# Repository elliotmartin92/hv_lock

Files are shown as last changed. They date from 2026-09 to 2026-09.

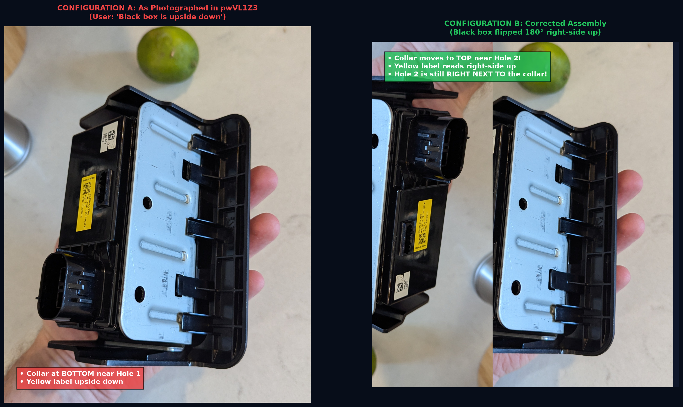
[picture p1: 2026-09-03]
testing/assembly_orientation_check.png

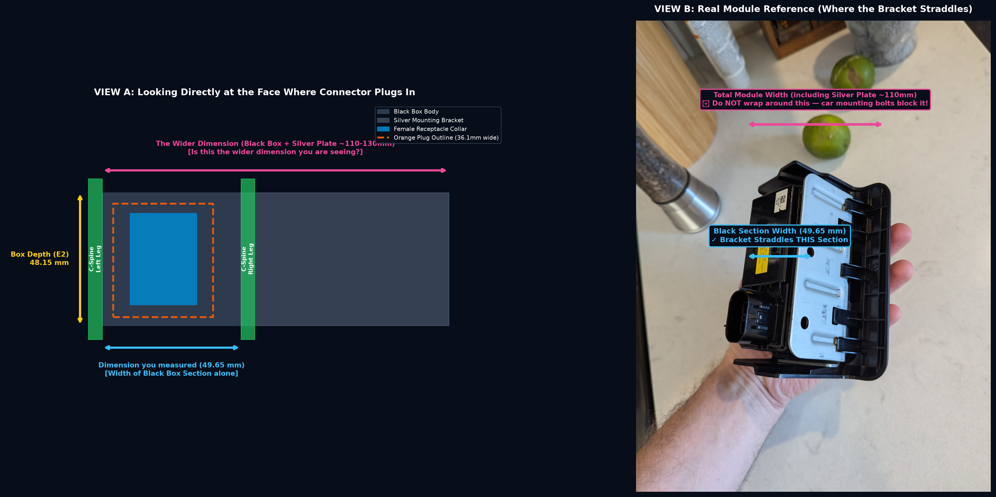
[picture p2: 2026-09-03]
testing/width_clarification.png

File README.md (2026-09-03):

# Kia EV6 / Hyundai E-GMP 95190-CV780 V2L Complete CAD System & Connector Lock

Comprehensive engineering repository containing high-fidelity, caliper-calibrated 3D CAD models of the vehicle outlet assembly, physical measurements ground truth, multimodal AI blueprints, and retention lock prototypes.

---

## 📂 Repository Structure

```text
hv_lock/
├── accurate_models/               # Master Caliper-Calibrated 3D CAD Models & AI Blueprints
│   ├── mated_assembly.stl         # Complete 3-part watertight mated assembly (8,708 faces)
│   ├── mated_assembly.obj         # 3-part assembly with materials & vertex colors
│   ├── mated_outer_housing.stl    # Outer cowl bezel & stamped aluminum bracket
│   ├── mated_outlet_box.stl       # Calibrated outlet box module
│   ├── mated_connector.stl        # Orange HV connector plug seated in receptacle collar
│   ├── mated_assembly_blueprint_ai.png # 5K Multimodal AI technical blueprint
│   ├── mated_assembly_blueprint_ai.json# Machine-readable metadata & coordinate anchors
│   ├── generate_ai_blueprint.py   # AI blueprint & JSON generator script
│   ├── build_accurate_models.py   # Master CAD synthesis script
│   ├── render_accurate_blueprints.py # Standard orthographic blueprint renderer
│   ├── outer_housing_measurements.json # Outer housing dimensional parameters
│   └── README_AI.md               # Detailed AI agent topology manual
│
├── caliper_measurements.csv       # Master physical caliper ground truth table
├── caliper_measurements.xlsx      # Formatted Excel workbook with calculations
├── README.md                      # Primary project overview (this file)
├── README_AI.md                   # AI topology atlas & datum reference guide
├── .gitignore                     # Git ignore rules
│
└── testing/                       # All Testing Scripts, Early Prototypes & Concept Iterations
    ├── chassis_bolt_lock.*        # Direct chassis bolt lock prototypes & prints
    ├── c_bracket.*                # 2-piece monolithic C-bracket prototypes & prints
    ├── exact_chassis_bolt_lock.*  # Calibrated chassis lock variations
    ├── concept1_notch_deadbolt.stl# Early concept 1 deadbolt
    ├── concept2_c_bracket_cage.stl# Early concept 2 cage
    ├── concept3_chassis_bracket_retainer.stl # Early concept 3 bracket
    ├── print_plate_all_parts.stl  # Combined print plates for prototype testing
    ├── build_*.py                 # Historical build scripts
    ├── illustrate_*.py            # Historical diagram generators
    ├── render_*.py                # Historical rendering scripts
    └── *.png                      # Historical test diagrams and blue prints
```

---

## 📐 Primary Production Deliverables (`accurate_models/`)

| File | Format | Description |
| :--- | :---: | :--- |
| **`mated_assembly.stl`** | STL (Binary) | Complete 3-part solid watertight assembly ($142.30 \times 166.71 \times 95.40\text{ mm}$) |
| **`mated_assembly.obj`** | OBJ | Multi-component assembly with materials, vertex colors, and normals |
| **`mated_outer_housing.stl`** | STL | Outer cowl bezel with smooth curved roof, $5.6^\circ$ wings, stamped aluminum plate |
| **`mated_outlet_box.stl`** | STL | Box enclosure seated $16.79\text{ mm}$ ahead of plate back ($3.04\text{ mm}$ hole clearance) |
| **`mated_connector.stl`** | STL | Orange HV connector plug seated in collar with confirmed $4.70\text{ mm}$ gap |
| **`mated_assembly_blueprint_ai.png`** | Image (5K) | Multimodal AI blueprint with all 35+ physical caliper measurement ties |
| **`mated_assembly_blueprint_ai.json`**| JSON | Machine-readable bounding boxes, datum reference frames, and tolerances |

---

## 🤖 AI & Multimodal System Reference

For AI agents, vision-language models, and automated CAD pipelines:
- Refer to [**`README_AI.md`**](README_AI.md) or [`accurate_models/README_AI.md`](accurate_models/README_AI.md) for full coordinate system specifications, topological constraints, and design rules for lock mechanisms.

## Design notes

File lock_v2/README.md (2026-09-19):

# Lock v2: Continuous Organic Connector Lock System
## Kia EV6 / Hyundai E-GMP 95190-CV780 High-Voltage V2L Outlet Connector Lock
### Anchored by Dual M6 Flanged Nuts (Ø 17.25 mm Built-In Washers) with Under-Box Clamping Toe

---

### 1. Engineering Highlights & Structural Architecture
**Lock v2** is a continuous, flow-formed automotive physical lock engineered from scratch for the high-voltage V2L connector.

In direct response to mechanical fatigue, installation ergonomics, and physical vehicle clearances:
1. **100% Open-Top U-Saddle (Zero Roof, Zero Closed Circles)**:
   - **No Closed Circles**: The base bracket cradle is completely open through the top and rear. The connector does **not** need to be threaded through any closed hole (which is physically impossible with a factory-wired vehicle cable).
   - **Direct Drop-In Installation**: The orange connector body nests directly into the lower cradle from above, resting securely on a solid PCTG saddle bed at \(Z = 52.10\text{ mm}\).
   - **Snug 30.0 mm Locating Channel**: The cradle guide channel ahead of the keeper is calibrated to **\(30.0\text{ mm}\) inside width** (\(0.50\text{ mm}\) precision slip-fit per side around the \(29.0\text{ mm}\) connector handle), completely eliminating twist, lateral play, and vibration rattle.
   - **Full Latch & CPA Access**: With zero top roof, the connector latch lever and red CPA slider remain 100% unobstructed and accessible.
   - **Massive Dual Guide Towers**: The cradle upright towers flanking the connector are **\(11.0 - 16.0\text{ mm}\) thick solid PCTG** on each side with \(R = 4.0\text{ mm}\) rounded corners, eliminating any thin, fragile, or flexing faces.

2. **Heavy-Duty Slide-In Retention Keeper (100% Open Inverted U-Fork • Genus = 0)**:
   - **Zero Closed Holes**: The keeper is a **100% open-bottom inverted U-fork** (\(\text{Genus} = 0\)). The bottom of the keeper is completely wide open with zero bottom bridge or floor.
   - **Drop-In Assembly**: Neither the connector head nor the cable needs to be threaded through any closed hole. Once the orange connector and cable drop into the open-top base bracket saddle, the keeper drops straight down over the cable boot from above.
    - **Robust Thickness**: **\(8.2\text{ mm}\) solid PCTG thickness** with an integrated **\(36.0\text{ mm}\) wide** ergonomic thumb grip tab.
    - **Calibrated Cable Throat**: Features a **\(19.0\text{ mm}\) wide inverted U-slot** centered at **\(X = +49.20\text{ mm}\)** that clears the \(\varnothing 17.0\text{ mm}\) corrugated conduit with \(+1.0\text{ mm}\) radial air gap and \(0.000000\text{ mm}^3\) collision volume.
    - **Bilateral 8.55 mm Bearing Shoulders (1.000 Symmetry Ratio)**:
      * Left Shoulder: Bears against connector shoulder from \(X = 31.15\text{ mm}\) to \(39.70\text{ mm}\) (\(8.55\text{ mm}\) solid contact).
      * Right Shoulder: Bears against connector shoulder from \(X = 58.70\text{ mm}\) to \(67.25\text{ mm}\) (\(8.55\text{ mm}\) solid contact).
      * Symmetrical Bearing Area: **\(\sim 325\text{ mm}^2\)** of solid PCTG bearing squarely against the rigid orange shoulder plane at **\(Y = -98.01\text{ mm}\)** (\(2.50\text{ mm}\) rearward relief easing cable bend tension), preventing any axial pullout or cocking.
    - **Precision Aligned Snap Detents**:
      * **Base Track Pockets (Female)**: Precision spherical pockets (\(R = 2.3\text{ mm}\)) subtracted directly into the track side walls at \(X = 30.90\text{ mm}\) and \(X = 67.50\text{ mm}\), \(Y = -102.11\text{ mm}\), \(Z = 58.00\text{ mm}\), with vertical lead-in guide channels.
      * **Keeper Bumps (Male)**: Symmetrical spherical bumps (\(R = 2.0\text{ mm}\)) protruding from the lateral side edges at \(X = 30.90\text{ mm}\) and \(X = 67.50\text{ mm}\), \(Y = -102.11\text{ mm}\), \(Z = 58.00\text{ mm}\).
      * **0.000 mm Alignment Error**: The detents line up identically in \(Y\) and \(Z\), sliding down smoothly and snapping together with a tactile "CLICK" that prevents vibration walkout.
    - **Toolless Release**: Simply pull straight up on the thumb tab to release the keeper for vehicle servicing.

3. **Accommodates OEM M6 Flanged Nuts with Built-In \(\varnothing 17.25\text{ mm}\) Washers**:
    - Flat flange seats allow OEM flanged nuts with their integrated \(\varnothing 17.25\text{ mm}\) washer to seat completely flush without edge binding.
    - Enclosed through-holes (\(\varnothing 7.20\text{ mm}\) Central / \(8.00 \times 7.20\text{ mm}\) Outer Slot) clamp the lock rigidly to the vehicle frame.
    - Unimpeded vertical socket tool clearance cylinders (\(\varnothing 18.50\text{ mm}\)) extend normal to the plate through the top of the bracket for direct access with a standard \(10\text{ mm}\) socket wrench.

4. **Extended Clamping Toe Underneath the Outlet Box**:
    - Because the nut's \(\varnothing 17.25\text{ mm}\) built-in washer reaches \(Y = -33.66\text{ mm}\) (\(2.55\text{ mm}\) forward of the outlet box rear wall at \(Y = -36.21\text{ mm}\)), the mounting foot extends forward to **\(Y = -28.00\text{ mm}\)** (\(8.21\text{ mm}\) underneath the outlet box).
    - Provides **\(5.66\text{ mm}\) of solid PCTG bearing material ahead of the washer rim**, supporting the primary forward compressive reaction load.
    - The foot thickness under the box is calibrated to \(2.80\text{ mm}\), leaving a verified **\(2.04\text{ mm}\) vertical air gap** below the flat underside of the outlet box (\(Z = 36.20\text{ mm}\)).
    - Acts as a continuous cantilever lever arm that prevents bracket tipping and transfers compressive clamping reaction directly into the vehicle floor plate.

5. **100% Flat Bolt Flange & Continuous Corridor Riser Spine Routing**:
    - **Eliminates Raised Turrets & Deep Sockets**: The bolt interface is **100% flat and planar** at \(Z_{\text{local}} = 2.80\text{ mm}\) starting at the bolt depressions. All raised bosses and counterbore walls have been eliminated to provide zero interference with the vehicle's stamped aluminum floor plate.
    - **Corridor Riser Spine Routing**: The continuous monocoque spine takes off from the center bolt zone and ascends cleanly through the clear corridor (\(X \in [6.0, 30.0]\text{ mm}\)) between the center bolt washer and the connector body (\(X \ge 31.15\text{ mm}\)), sweeping into the cradle behind the shoulder (\(Y \le -98.01\text{ mm}\)). This delivers strictly **\(0.000000\text{ mm}^3\) collision volume** across Outer Housing, Outlet Box, and Connector.
    - **Calibrated 28.0 mm Offset Realignment**: Realigned from physical vehicle test-fitting: shifted **\(28.00\text{ mm}\) cabin left** (\(X = 21.20\text{ mm} \to \mathbf{X = +49.20\text{ mm}\)), perfectly coaxial with the vehicle connector and eliminating lateral cable bending strain.
    - **2.50 mm Fore-Aft Reach Relief**: The retention shoulder plane is eased rearward from \(Y = -95.51\text{ mm}\) to **\(Y = -98.01\text{ mm}\)**, providing reach relief to eliminate excessive cable boot compression.

```text
               VEHICLE INTERIOR (+Y)
                         │
        ┌────────────────▼────────────────┐
        │   Outlet Box Bottom (Z = 36.20) │
        └────────────────┬────────────────┘
                         │ 2.04 mm Air Gap
        ┌────────────────▼────────────────┐
        │   Extended Clamping Toe         │  Extends to Y = -28.0 mm (8.21 mm under box);
        │   (5.66 mm solid ahead of nut)  │  2.80 mm thick PCTG compression shelf.
        └────────────────┬────────────────┘
                         │ M6 Flanged Nuts with Ø 17.25 mm built-in washer
        ┌────────────────▼────────────────┐
        │   lock_v2_base_bracket.stl      │  Continuous filleted mounting foot;
        │   (Continuous Flow-Formed Solid)│  100% flush 5.87° pitch; R=3-6mm fillets.
        └────────────────┬────────────────┘
                         │ Continuous organic Wishbone/A-frame spine
        ┌────────────────▼────────────────┐
        │   Open-Top U-Saddle & Towers    │  100% OPEN TOP: Zero roof, zero closed circle!
        │   (12 mm thick side towers)     │  Connector drops in directly from above.
        └────────────────┬────────────────┘
                         │ Vertical slide-in from above (+Z)
        ┌────────────────▼────────────────┐
        │   lock_v2_keeper.stl            │  Robust 8.2 mm solid PCTG gate;
        │   (Slide Retention Gate)        │  Inverted U-slot traps boot; locks shoulder!
        └─────────────────────────────────┘
                         │
               DASHBOARD CAVITY (-Y)
```

---

### 2. Dimensional Ground Truth & Clearance Matrix

All geometry strictly references [`accurate_models/README_AI.md`](file:///c:/Users/Elliot/Documents/antigravity/hv_lock/accurate_models/README_AI.md) and [`accurate_models/mated_assembly_blueprint_ai.json`](file:///c:/Users/Elliot/Documents/antigravity/hv_lock/accurate_models/mated_assembly_blueprint_ai.json):

| Metric / Feature | Ground Truth Value | Lock v2 Continuous Value | Engineering Function |
| :--- | :--- | :--- | :--- |
| **Cradle Top Roof** | None (open space) | **100% Open Top (Zero Roof)** | Unobstructed latch access; drop-in installation |
| **Rear Cable Passage** | Hardwired cable | **Open U-Channel (Zero Closed Circles)**| Cable drops into saddle from above |
| **Keeper Body Thickness**| N/A | **\(8.2\text{ mm}\) Solid PCTG** | Heavy-duty axial retention gate |
| **Thumb Grip Thickness** | N/A | **\(12.2\text{ mm}\) Solid PCTG** | Ergonomic ribbed grip tab |
| **Nut Washer Diameter** | **\(\varnothing 17.25\text{ mm}\)** built-in | **\(\varnothing 18.50\text{ mm}\)** counterbore seat | Full flush washer seating without edge binding |
| **Solid Margin Ahead of Nut** | Overhangs box by \(2.55\text{ mm}\) | **\(5.66\text{ mm}\)** solid PCTG ahead of washer | Prevents shearing & edge crushing |
| **Under-Box Extension** | Box rear wall at \(Y = -36.21\text{ mm}\) | Foot reaches **\(Y = -28.00\text{ mm}\)** (\(8.21\text{ mm}\) under box) | Extended anti-tipping cantilever toe |
| **Vertical Headroom Under Box**| Box bottom at \(Z = 36.20\text{ mm}\) | Foot top max \(Z = 34.16\text{ mm}\) (**\(2.04\text{ mm}\) clearance**) | Meets user requirement of \(\ge 2\text{ mm}\) clearance |
| **Central Bolt Hole `[H15d]`** | \(\varnothing 6.45\text{ mm}\) at \((+5.28, -42.29, 30.87)\) | \(\varnothing 7.20\text{ mm}\) enclosed through-bore | Captive M6 through-bolt clamping |
| **Outer Slot `[H15b]`** | \(7.45 \times 6.45\text{ mm}\) at \((-39.63, -42.59, 30.90)\) | \(8.00 \times 7.20\text{ mm}\) enclosed through-slot | Captive M6 through-bolt anti-rotation |
| **Dual Bolt Center Span `[H15e]`**| **\(44.90\text{ mm}\)** | **\(44.90\text{ mm}\)** exact spacing (\(0.00\text{ mm}\) center offset) | Direct chassis anchoring |
| **Aluminum Plate Angle `[H16c]`** | **\(5.87^\circ\)** upward pitch | **\(5.87^\circ\)** matched base foot pitch | 100% flush bearing contact |
| **Connector Seated Gap `[GAP]`** | \(4.70\text{ mm}\) clearance | Leaves \(4.70\text{ mm}\) undisturbed | Factory seal compression maintained |
| **Connector Rigid Length `[B7]`**| \(54.60\text{ mm}\) | Shoulder plane locked at **\(Y = -98.01\text{ mm}\)** (\(2.50\text{ mm}\) reach relief) | Positive mechanical axial stop |
| **Shoulder Bearing Overlap** | None (loose in prototype) | **2x \(8.55\text{ mm}\) Bilateral Shoulders** (\(\sim 325\text{ mm}^2\)) | Symmetrical balanced axial retention |
| **Bilateral Symmetry Ratio** | Asymmetric in early build | **1.000 (Exact 50/50 load sharing)** | Eliminates cantilever yaw / twisting |
| **Cradle Centerline** | \(X = 21.20\text{ mm}\) (early test-fit) | **\(X = +49.20\text{ mm}\)** (\(28.00\text{ mm}\) cabin left calibration) | Directly coaxial with vehicle connector |
| **Bolt Mounting Interface** | Raised \(8.5\text{ mm}\) turrets | **100% Flat Flange (\(2.80\text{ mm}\))** starting at bolt depressions | Zero interference with aluminum plate |
| **Cradle Guide Channel** | \(38.5\text{ mm}\) wide (\(9.5\text{ mm}\) slop) | **\(30.0\text{ mm}\) Snug Channel** (\(0.50\text{ mm}\) slip-fit) | Prevents side-to-side wiggle and rattle |
| **Cable Boot Clearance** | \(\varnothing 17.00\text{ mm}\) rubber boot | \(\varnothing 19.00\text{ mm}\) U-slot (\(1.0\text{ mm}\) radial air gap) | Smooth lead-in, zero cable chafing |
| **Outer Housing Wings** | Inner span \(140.50\text{ mm}\) \([H11]\) | Lock width \(105.71\text{ mm}\) (\(>17\text{ mm}\) air gap to wings) | Ample lateral clearance |
| **Roof Arch Margin** | Roof arch apex at \(Z = 95.40\text{ mm}\) | Max lock height \(Z = 81.00\text{ mm}\) (\(14.40\text{ mm}\) clearance) | Fits easily inside dash aperture |

---

### 3. File Deliverables in `lock_v2/`

| File | Format | Description |
| :--- | :--- | :--- |
| [`build_lock_v2.py`](file:///c:/Users/Elliot/Documents/antigravity/hv_lock/lock_v2/build_lock_v2.py) | Python 3.13 | Master CAD script utilizing `manifold3d` for continuous organic modeling |
| [`render_lock_v2_blueprints.py`](file:///c:/Users/Elliot/Documents/antigravity/hv_lock/lock_v2/render_lock_v2_blueprints.py) | Python 3.13 | High-resolution 4-panel technical blueprint generator |
| [`lock_v2_base_bracket.stl`](file:///c:/Users/Elliot/Documents/antigravity/hv_lock/lock_v2/lock_v2_base_bracket.stl) | 3D STL (Solid) | Open-top U-saddle base with under-box toe & \(\varnothing 18.50\text{ mm}\) nut seats |
| [`lock_v2_base_bracket.obj`](file:///c:/Users/Elliot/Documents/antigravity/hv_lock/lock_v2/lock_v2_base_bracket.obj) | Wavefront OBJ | Base bracket with anodized blue material vertex colors |
| [`lock_v2_keeper.stl`](file:///c:/Users/Elliot/Documents/antigravity/hv_lock/lock_v2/lock_v2_keeper.stl) | 3D STL (Solid) | Robust \(8.2\text{ mm}\) solid PCTG slide-in retention gate with snap detents |
| [`lock_v2_keeper.obj`](file:///c:/Users/Elliot/Documents/antigravity/hv_lock/lock_v2/lock_v2_keeper.obj) | Wavefront OBJ | Keeper with safety green material vertex colors |
| [`lock_v2_1piece_monolithic.stl`](file:///c:/Users/Elliot/Documents/antigravity/hv_lock/lock_v2/lock_v2_1piece_monolithic.stl) | 3D STL (Solid) | 1-piece through-bolted alternative lock with side-entry cable collar |
| [`lock_v2_1piece_monolithic.obj`](file:///c:/Users/Elliot/Documents/antigravity/hv_lock/lock_v2/lock_v2_1piece_monolithic.obj) | Wavefront OBJ | Monolithic lock with royal purple material vertex colors |
| [`lock_v2_mated_verification.stl`](file:///c:/Users/Elliot/Documents/antigravity/hv_lock/lock_v2/lock_v2_mated_verification.stl) | 3D STL (Assembly) | Complete vehicle mated assembly + Lock + M6 flanged nuts |
| [`lock_v2_mated_verification.obj`](file:///c:/Users/Elliot/Documents/antigravity/hv_lock/lock_v2/lock_v2_mated_verification.obj) | Wavefront OBJ | Color-coded full mated verification assembly |
| [`lock_v2_print_plate.stl`](file:///c:/Users/Elliot/Documents/antigravity/hv_lock/lock_v2/lock_v2_print_plate.stl) | 3D STL (Plated) | Pre-arranged flat on build plate for Bambu P1S (0% supports) |
| [`lock_v2_blueprint.png`](file:///c:/Users/Elliot/Documents/antigravity/hv_lock/lock_v2/lock_v2_blueprint.png) | 5K PNG Image | 4-panel AI multimodal technical blueprint with callouts |

---

### 4. Bambu Lab P1S Slicer Settings & Print Plate Orientation

- **Print Plate Orientation (`lock_v2_print_plate.stl`)**:
  * **Base Bracket**: Pre-oriented **100% flat on its wide \(1707\text{ mm}^2\) mounting foot** (\(Z = 0\)).
    - *Hoop Strength*: M6 through-bores and counterbores print vertically as continuous concentric perimeter loops, maximizing hoop tensile strength against bolt torque.
    - *Clamp Compression*: Compressive clamping reaction from the \(\varnothing 17.25\text{ mm}\) flanged nuts acts directly perpendicular to layers, eliminating inter-layer shear risk.
    - *Minimal Supports*: The Wishbone spine rises at a gentle \(35^\circ - 40^\circ\) angle from the bed, printing cleanly with minimal or zero supports.
  * **Slide Keeper**: Pre-oriented **100% flat on its wide \(1351\text{ mm}^2\) front bearing face** (\(Z = 0\)).
    - *Flexural Strength*: Continuous filament strands run across the cantilever snap detent tabs in the XY plane, maximizing flexural fatigue endurance.
    - *Zero Supports*: Low profile (\(12.2\text{ mm}\) total height) requires 0% supports.
  * **Combined Bed Contact Area**: **\(3501.1\text{ mm}^2\)** of planar contact for rock-solid bed adhesion on the textured PEI plate.

- **Material Selection**: **PCTG** (e.g. Fiberlogy PCTG or Bambu PCTG)
- **Nozzle**: \(0.4\text{ mm}\) Hardened Steel
- **Bed Surface**: Textured PEI Plate (\(80^\circ\text{C} - 85^\circ\text{C}\))
- **Nozzle Temperature**: \(255^\circ\text{C} - 265^\circ\text{C}\)
- **Layer Height**: \(0.20\text{ mm}\) Strength Profile
- **Wall Loops (Perimeters)**: **6 walls** (\(2.4\text{ mm}\) solid shell)
- **Top / Bottom Shell Layers**: 5 top layers, 5 bottom layers (\(1.0\text{ mm}\) solid skins)
- **Infill**: **40% Gyroid** or **Cross-Hatch**
- **Supports**: **0% (Disabled)** — both parts are pre-oriented flat on their largest planar faces for support-free printing.

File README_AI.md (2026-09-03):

# AI AGENT & MULTIMODAL SYSTEM DIRECTIVE: SYSTEM TOPOLOGY & CAD ASSET ATLAS
## Kia EV6 / Hyundai E-GMP 95190-CV780 V2L Vehicle Outlet & Mated Assembly

This document is the authoritative machine-readable and cognitive guide for AI agents, vision-language models, and automated engineering pipelines interacting with this repository.

---

### 1. DATUM REFERENCE FRAME & COORDINATE SYSTEM

All CAD models (`.stl`, `.obj`), blueprint projections, and mathematical constraints adhere strictly to this right-handed Cartesian coordinate system:

| Axis | Orientation & Sign | Origin ($0.0, 0.0, 0.0$) | Engineering Interpretation |
| :--- | :--- | :--- | :--- |
| **X** | **+X**: Vehicle Right (Passenger)<br>**-X**: Vehicle Left (Driver) | Centerline of lateral symmetry | **Perspective Note**: A person standing in the passenger cabin looking directly into the outlet module sees **Vehicle Left (+X world)** on their **left**, and **Vehicle Right (-X world)** on their **right**. |
| **Y** | **+Y**: Forward (into Cabin)<br>**-Y**: Rearward (into Dash Interior) | Front-most finished face of outer cowl bezel | $Y = 0.0$ is the cabin boundary plane. All structural cavity components, brackets, and wiring extend along $-Y$. |
| **Z** | **+Z**: Upward (towards Vehicle Roof)<br>**-Z**: Downward (towards Floorpan) | Bottom edge of lower bezel chin | $Z = 0.0$ is the lowest point of the plastic trim. The smooth curved roof arch peaks at $Z = +95.40\text{ mm}$. |

---

### 2. SYSTEM ARCHITECTURE & 3-PART MATED TOPOLOGY

The system consists of three precisely mated physical subsystems located at:
`c:\Users\Elliot\Documents\antigravity\hv_lock\accurate_models\`

```text
       CABIN INTERIOR (+Y)
               │
   ┌───────────▼───────────┐
   │  Outer Housing Bezel  │  X in [-71.15, +71.15], Z in [0, 95.40], Y in [-58.80, 0.0]
   │  & Stamped Aluminum   │  Window: X in [-57.30, +57.30], Z in [34.00, 84.20]
   └───────────┬───────────┘
               │ Seated in window recess at Y = -3.00 mm
   ┌───────────▼───────────┐
   │   AC Outlet Box Body  │  X in [-55.88, +55.88], Z in [36.20, 82.20], Y in [-36.21, -3.00]
   │   [H17a]: 16.79 mm Gap│  Holes on plate completely exposed ahead of Y = -36.21 mm!
   │   [H17b]:  9.10 mm Gap│  Bottom of box sits 9.10 mm vertically off aluminum plate.
   └───────────┬───────────┘
               │ Collar extends along -Y from Y = -36.21 to Y = -58.58 mm at X = +27.0 mm
   ┌───────────▼───────────┐
   │  Orange HV Connector  │  Plug body: X in [+6.55, +47.45], Y in [-95.51, -40.91]
   │  [GAP]: 4.70 mm Seated│  Plugs into collar; 17.67 mm penetration inside connector shroud.
   │  Rear Flexible Cable  │  Corrugated conduit & cable extends rearward to Y = -165.91 mm.
   └───────────────────────┘
               │
      DASHBOARD INTERIOR (-Y)
```

#### A. Subsystem 1: Outer Housing Bezel & Stamped Aluminum Frame
- **File**: `mated_outer_housing.stl` / `outer_housing_model.stl`
- **Bounding Box**: $X \in [-71.15, +71.15]\text{ mm}$ ($142.30\text{ mm}$ `[H1]`), $Y \in [-58.80, 0.0]\text{ mm}$ ($58.80\text{ mm}$ `[H7a]`), $Z \in [0.0, 95.40]\text{ mm}$ ($95.40\text{ mm}$ `[H2]`).
- **Roof Profile**: 100% smooth continuous curved arch. Wings never extend above the roof arch.
- **Window Aperture**: $114.60\text{ mm}$ wide `[H3]` $\times 50.20\text{ mm}$ high `[H4]`, spanning $Z \in [34.00, 84.20]\text{ mm}$. Recessed internal step at $Y = -3.00\text{ mm}$ `[H14]`.
- **Lower Chin**: Protrudes $30.77\text{ mm}$ high `[H5]` at front, $7.10\text{ mm}$ total depth `[H5b]`. Extends $27.10\text{ mm}$ vertically below the aluminum plate root `[H16f]`.
- **Side Wings**: Inner clear air span $140.50\text{ mm}$ `[H11]`, wall thickness $2.60\text{ mm}$ `[H13]`. Front edge at $Z = 88.50\text{ mm}$, slopes gently by $5.0\text{ mm}$ ($5.6^\circ$) to $Z = 83.50\text{ mm}$ at $Y = -58.80\text{ mm}$. Bottom edge terminates flush with window bottom at $Z = 34.00\text{ mm}$ (never extends below the aluminum plate).
- **Stamped Aluminum Plate**:
  - Width: $120.20\text{ mm}$ `[H12]` ($10.15\text{ mm}$ air gap `[H11b]` to each side wing).
  - Root Bend: Located at $Y = -5.60\text{ mm}, Z = 27.10\text{ mm}$ ($6.90\text{ mm}$ below window sill `[H16g]`).
  - Internal Bend Angle: $84.13^\circ$ `[H16b]` ($5.87^\circ$ upward pitch `[H16c]` towards ceiling).
  - Rear Extension: Extends to $Y = -53.00\text{ mm}$ `[H10]`, rear edge elevated to $Z = 31.97\text{ mm}$.
  - Chassis Bolt Holes:
    - **Central Hole `[H15d]`**: Round circular hole, $\varnothing 6.45\text{ mm}$, centered at $X = +5.28\text{ mm}, Y = -45.40\text{ mm}$ ($7.60\text{ mm}$ from back edge `[H15f]`).
    - **Outer Slot `[H15b]`**: Horizontal oval slot, $7.45\text{ mm}$ wide (X) $\times 6.45\text{ mm}$ high (Y), centered at $X = -39.63\text{ mm}, Y = -45.70\text{ mm}$ ($16.75\text{ mm}$ from side `[H15a]`, $7.30\text{ mm}$ from back edge `[H15g]`).
    - **Center-to-Center Spacing `[H15e]`**: $44.90\text{ mm}$. Edge-to-edge clear spacing `[H15c]`: $37.95\text{ mm}$.

#### B. Subsystem 2: AC Outlet Box Module
- **File**: `mated_outlet_box.stl` / `outlet_box_model.stl`
- **Body Bounding Box**: $X \in [-55.88, +55.88]\text{ mm}$ ($111.75\text{ mm}$ wide), $Y \in [-36.21, -3.00]\text{ mm}$ ($33.21\text{ mm}$ depth), $Z \in [36.20, 82.20]\text{ mm}$ ($46.00\text{ mm}$ height).
- **Cabin Faceplate Layout (Front View looking in -Y direction)**:
  - **LEFT Side (+X world / Screen Left)**: Spring-loaded flap door ("Max AC 120V, 16A") centered at $X = +27.0\text{ mm}$.
  - **RIGHT Side (-X world / Screen Right)**: Circular NEMA 5-15R 120V AC 3-prong outlet socket centered at $X = -27.0\text{ mm}$.
- **Rear Clearance to Aluminum Plate (`[H17a]`)**:
  - The back wall of the box stops at $Y = -36.21\text{ mm}$, exactly **$16.79\text{ mm}$ ahead** of the rear edge of the aluminum plate ($Y = -53.00\text{ mm}$).
  - Because the mounting holes span $Y \in [-45.70, -39.25]\text{ mm}$, having the back wall at $-36.21\text{ mm}$ provides **$3.04\text{ mm}$ of clear space ahead of the holes**. The chassis bolt holes are **100% unobstructed and accessible from above**.
- **Vertical Gap off Aluminum Plate (`[H17b]`)**:
  - The box bottom is elevated to $Z = 36.20\text{ mm}$, providing a **$9.10\text{ mm}$ vertical air gap** above the aluminum plate root ($Z = 27.10\text{ mm}$).
  - Within the $50.20\text{ mm}$ window opening ($Z \in [34.00, 84.20]\text{ mm}$), the box sits with a $2.20\text{ mm}$ bottom margin and a $2.00\text{ mm}$ top margin, vertically centered.
- **Receptacle Collar**:
  - Protrudes from the rear wall at $X = +27.0\text{ mm}$ (on the LEFT flank behind the flap door).
  - Cross-section: Outer width $22.70\text{ mm}$ `[D1]`, outer height $33.05\text{ mm}$ `[D2]`.
  - Protrusion: Extends $22.37\text{ mm}$ along $-Y$ `[C1]` from $Y = -36.21\text{ mm}$ to $Y = -58.58\text{ mm}$.
  - Latch Tooth: Located on top ($+Z$ face) at $Y = -44.94\text{ mm}$ ($8.73\text{ mm}$ from collar rim `[C2]`), width $2.00\text{ mm}$ `[C3]`, height $2.70\text{ mm}$ `[C4]`.

#### C. Subsystem 3: Orange HV Cable Connector Plug
- **File**: `mated_connector.stl` / `connector_model.stl`
- **Plug Bounding Box**: $X \in [+6.55, +47.45]\text{ mm}$ (centered at $X = +27.0\text{ mm}$), $Z \in [40.65, 77.75]\text{ mm}$ ($37.11\text{ mm}$ total height `[A4]`), $Y \in [-165.91, -40.91]\text{ mm}$.
- **Seated Engagement**:
  - Front shroud rim is seated at $Y = -40.91\text{ mm}$.
  - Seated Gap `[GAP]`: $4.70\text{ mm}$ between the connector shroud rim and the back of the outlet box ($Y = -36.21\text{ mm}$).
  - Collar Penetration: The receptacle collar penetrates $17.67\text{ mm}$ inside the female connector shroud cavity.
- **Rigid Body vs Flexible Cable**:
  - Rigid body extends $54.60\text{ mm}$ `[B7]` from $Y = -40.91\text{ mm}$ to $Y = -95.51\text{ mm}$.
  - Yellow spiral wrap and high-voltage cable extend rearward to $Y = -165.91\text{ mm}$.

#### D. Complete Mated Assembly Solid
- **Files**: `mated_assembly.stl` (Binary STL) & `mated_assembly.obj` (Wavefront OBJ with materials/colors)
- **Bounding Box**: $142.30\text{ mm}\text{ (W)} \times 166.71\text{ mm}\text{ (D)} \times 95.40\text{ mm}\text{ (H)}$.
- **Watertight Status**: Solid manifold geometry ($8,708\text{ faces}$).

---

### 3. COMPLETE CALIPER MEASUREMENT GROUND TRUTH DICTIONARY

Every caliper measurement taken during physical teardown is indexed below and tied to its respective geometric entity:

| Label | Physical Dimension Name | Value | Tolerance | Geometric Entity / Assembly Constraint |
| :--- | :--- | :--- | :--- | :--- |
| **`[H1]`** | Total Outer Frame Width | **142.30 mm** | $\pm 0.20$ | Widest lateral span of the outer cowl bezel |
| **`[H2]`** | Total Outer Frame Height | **95.40 mm** | $\pm 0.20$ | $Z = 0$ (chin tip) to $Z = 95.40$ (continuous curved roof arch) |
| **`[H3]`** | Window Aperture Width | **114.60 mm** | $\pm 0.15$ | Internal opening width framing the $111.75\text{ mm}$ box |
| **`[H4]`** | Window Aperture Height | **50.20 mm** | $\pm 0.15$ | Internal opening height framing the $46.00\text{ mm}$ box |
| **`[H5]`** | Lower Chin Front Height | **30.77 mm** | $\pm 0.20$ | Front visible height of bottom trim bar |
| **`[H5b]`**| Chin Total Depth (w/ ribs) | **7.10 mm** | $\pm 0.15$ | Thickness from front bezel face back to aluminum root |
| **`[H6]`** | Top Bezel Thickness | **11.20 mm** | $\pm 0.15$ | Distance from top of window to apex of roof arch |
| **`[H7a]`**| Side Wing Total Depth | **58.80 mm** | $\pm 0.25$ | Maximum depth of side wings along $-Y$ |
| **`[H9]`** | Top Shelf Flat Length | **34.00 mm** | $\pm 0.30$ | Horizontal flat segment of roof before gentle slope |
| **`[H10]`**| Aluminum Rear Extension | **53.00 mm** | $\pm 0.25$ | Rearmost edge of aluminum plate at $Y = -53.00\text{ mm}$ |
| **`[H11]`**| Inner Wing Clear Span | **140.50 mm** | $\pm 0.20$ | Clear lateral span between interior faces of wings |
| **`[H11b]`**| Wing-to-Aluminum Air Gap| **10.15 mm** | $\pm 0.15$ | Horizontal space between plate side edge and wing inner face |
| **`[H12]`**| Aluminum Plate Width | **120.20 mm** | $\pm 0.20$ | $140.50 - 2 \times 10.15 = 120.20\text{ mm}$ |
| **`[H13]`**| Side Wing Wall Thickness | **2.60 mm** | $\pm 0.10$ | Molded ABS wing wall thickness |
| **`[H14]`**| Window Recess Step Depth | **3.00 mm** | $\pm 0.15$ | Depth offset where outlet box seating lip rests |
| **`[H15a]`**| Outer Slot Side Offset | **16.75 mm** | $\pm 0.15$ | From aluminum edge to outer edge of oval slot |
| **`[H15b]`**| Outer Oval Slot | **7.45 x 6.45 mm**| $\pm 0.10$ | Horizontal oval slot ($X = 7.45\text{ mm}$, $Y = 6.45\text{ mm}$) |
| **`[H15c]`**| Holes Edge-to-Edge Spacing| **37.95 mm** | $\pm 0.15$ | Clear metal span between circular hole and oval slot |
| **`[H15d]`**| Central Hole Diameter | **Ø 6.45 mm** | $\pm 0.10$ | Circular chassis bolt hole |
| **`[H15e]`**| Holes Center-to-Center | **44.90 mm** | $\pm 0.15$ | Center-to-center lateral hole spacing |
| **`[H15f]`**| Central Hole Back Distance| **7.60 mm** | $\pm 0.15$ | From rear edge of aluminum plate to circular hole center |
| **`[H15g]`**| Oval Slot Back Distance | **7.30 mm** | $\pm 0.15$ | From rear edge of aluminum plate to oval slot center |
| **`[H16b]`**| Internal Bend Angle | **84.13°** | $\pm 0.25^\circ$| Calibrated from traced $67.0\text{ mm}$ chord ($2\arcsin(67/100)$) |
| **`[H16c]`**| Upward Pitch Angle | **5.87°** | $\pm 0.25^\circ$| $90.00^\circ - 84.13^\circ = 5.87^\circ$ upward inclination |
| **`[H16f]`**| Chin Extension Below Plate| **27.10 mm** | $\pm 0.20$ | Vertical distance from plate root down to chin tip |
| **`[H16g]`**| Plate Below Window Aperture| **6.90 mm** | $\pm 0.15$ | Vertical drop from window sill down to plate root |
| **`[H17a]`**| Box to Plate Back Clearance| **16.79 mm** | $\pm 0.15$ | Box back wall at $Y = -36.21\text{ mm}$; holes 100% uncovered! |
| **`[H17b]`**| Box Vertical Gap off Plate | **9.10 mm** | $\pm 0.20$ | Vertical air gap between plate root and box bottom |
| **`[A1]`** | Connector Shroud Outer Width| **36.10 mm** | $\pm 0.15$ | Shroud oval body width (40.90 mm including key rib) |
| **`[A4]`** | Total Plug Height | **37.11 mm** | $\pm 0.15$ | Overall vertical height including top latch tower |
| **`[B1]`** | Tower Axial Length | **36.75 mm** | $\pm 0.20$ | Length of the latch tower housing |
| **`[B7]`** | Connector Rigid Length | **54.60 mm** | $\pm 0.25$ | Front shroud rim to rear cable entry seal |
| **`[C1]`** | Collar Protrusion Length | **22.37 mm** | $\pm 0.15$ | Receptacle collar extension from back of outlet box |
| **`[C2]`** | Latch Tooth Distance | **8.73 mm** | $\pm 0.15$ | From collar rear rim to latch tooth center |
| **`[C3]`** | Latch Tooth Width | **2.00 mm** | $\pm 0.10$ | Lateral width of retention tooth |
| **`[C4]`** | Latch Tooth Height | **2.70 mm** | $\pm 0.10$ | Vertical protrusion height above collar top wall |
| **`[D1]`** | Collar Outer Width | **22.70 mm** | $\pm 0.15$ | Lateral width of receptacle collar |
| **`[D2]`** | Collar Outer Height | **33.05 mm** | $\pm 0.15$ | Vertical height of receptacle collar |
| **`[GAP]`**| Confirmed Seated Gap | **4.70 mm** | $\pm 0.10$ | Clearance between plug shroud rim and outlet box rear wall |

---

### 4. REPOSITORY FILE INVENTORY

All assets in [`accurate_models/`](file:///c:/Users/Elliot/Documents/antigravity/hv_lock/accurate_models):

| Filename | Type | Description |
| :--- | :--- | :--- |
| `mated_assembly.stl` | 3D CAD | Complete 3-part watertight assembly ($8,708\text{ faces}$) |
| `mated_assembly.obj` | 3D CAD | Pre-aligned 3-part assembly with vertex colors / materials |
| `mated_outer_housing.stl` | 3D CAD | Outer cowl bezel + stamped aluminum bracket |
| `mated_outlet_box.stl` | 3D CAD | Outlet box module seated at exact $Y=-36.21, Z=36.20\text{ mm}$ |
| `mated_connector.stl` | 3D CAD | Orange HV connector seated in collar ($4.70\text{ mm}$ gap) |
| `mated_assembly_blueprint_ai.png` | Image (5K) | High-contrast multimodal AI technical blueprint with all callouts |
| `mated_assembly_blueprint_ai.json`| Data | Structured machine-readable schema of all bounding boxes & labels |
| `generate_ai_blueprint.py` | Script | Python script that regenerates the AI blueprint & JSON |
| `build_accurate_models.py` | Script | Master CAD synthesis script generating all watertight STLs & OBJs |
| `render_accurate_blueprints.py` | Script | Standard 4-panel engineering orthographic rendering script |
| `outer_housing_measurements.json`| Data | JSON store of outer housing dimensions and physical parameters |
| `../caliper_measurements.csv` | Data | Master tabular CSV record of all physical measurements |
| `../caliper_measurements.xlsx`| Data | Master Excel workbook with calculations and formulas |

---

### 5. RULES FOR AI AGENTS DESIGNING RETENTION LOCK MECHANISMS

When creating or modifying physical mechanical lock components (e.g. anti-theft deadbolts, C-brackets, saddle clamps):

1. **Chassis Fastening Anchor**: The two mounting holes in the stamped aluminum plate at $Y \in [-45.70, -39.25]\text{ mm}$ are **100% uncovered** and available for mechanical through-bolts or threaded clamping studs.
2. **Connector Interlock**: A retention jaw can capture the connector rigid shoulder ($Y \in [-95.51, -40.91]\text{ mm}$) and lock against the back of the outlet box ($Y = -36.21\text{ mm}$) across the $4.70\text{ mm}$ seated gap.
3. **Lateral Clearance**: Maintain $\ge 1.0\text{ mm}$ clearance from the inner faces of the outer housing wings ($X = \pm 70.25\text{ mm}$) and $\ge 2.0\text{ mm}$ clearance above the sloping wing bottom edge ($Z = 34.00\text{ mm}$).
4. **Tool Access**: Any bolt securing the lock from the top must have clear vertical tool access within the window aperture ($X \in [-57.30, +57.30], Z > 34.00\text{ mm}$) or through the open rear chassis frame.

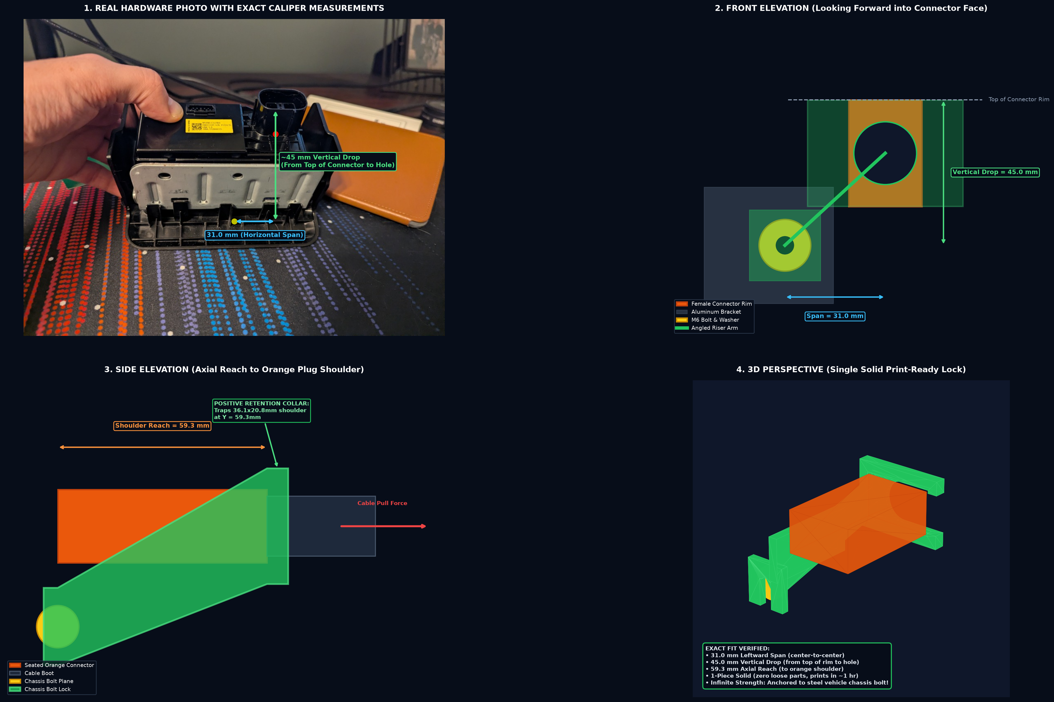
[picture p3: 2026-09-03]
testing/exact_chassis_bolt_lock_blueprint.png

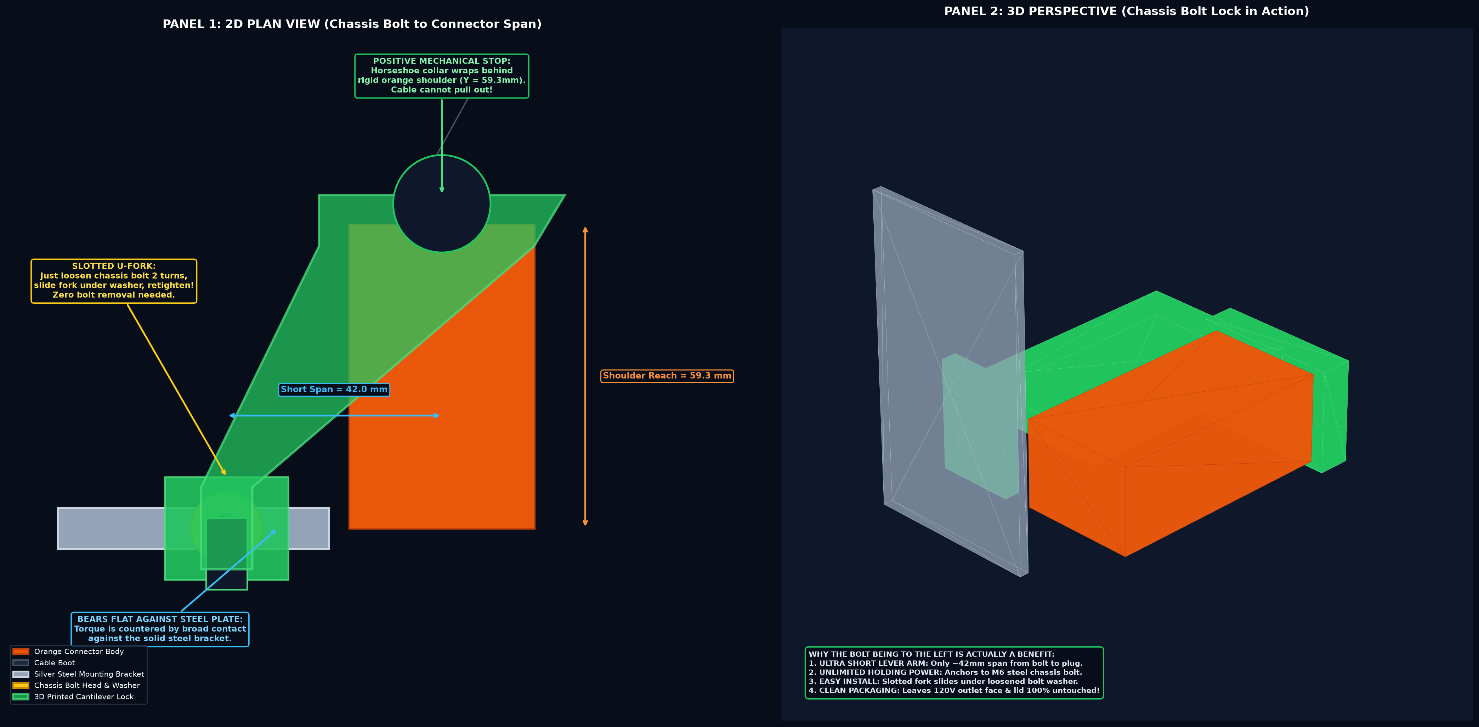
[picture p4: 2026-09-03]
testing/chassis_bolt_lock.png

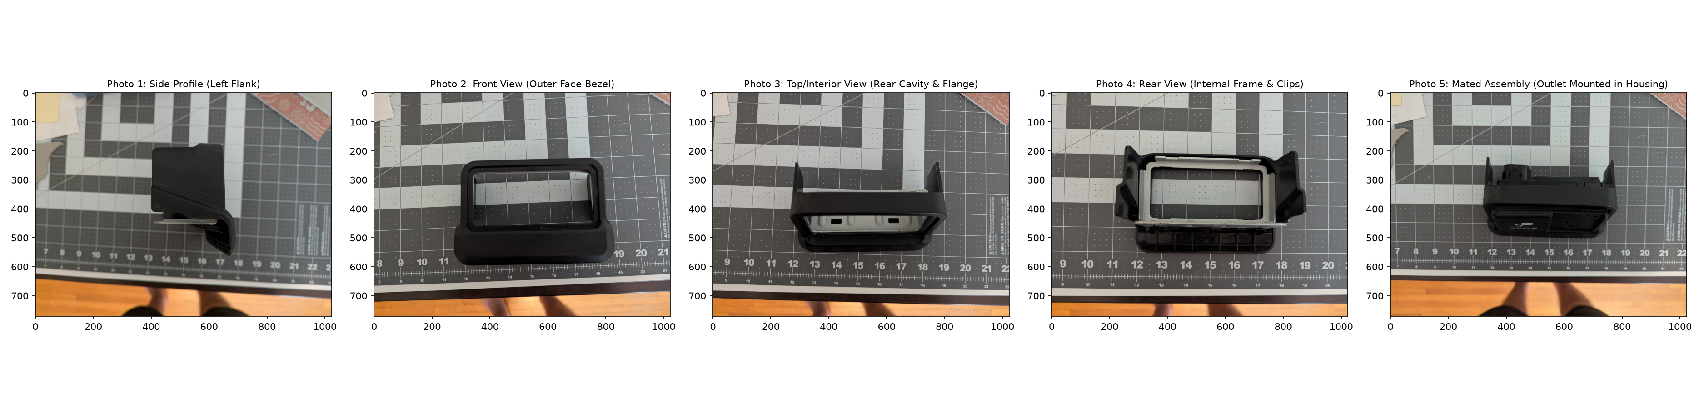
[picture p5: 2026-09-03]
accurate_models/photo_overview.png

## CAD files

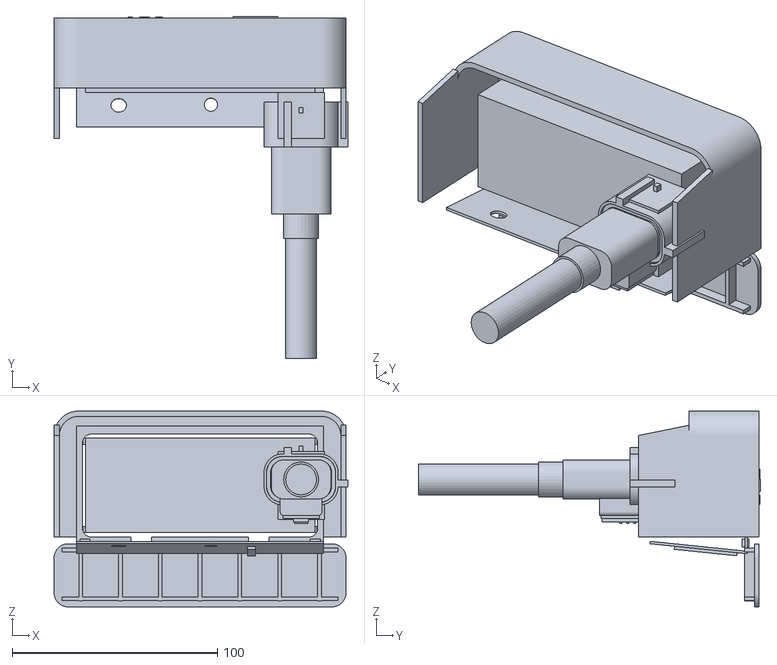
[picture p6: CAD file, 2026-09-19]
accurate_models/mated_assembly.stl
143.2 x 166.7 x 95.4

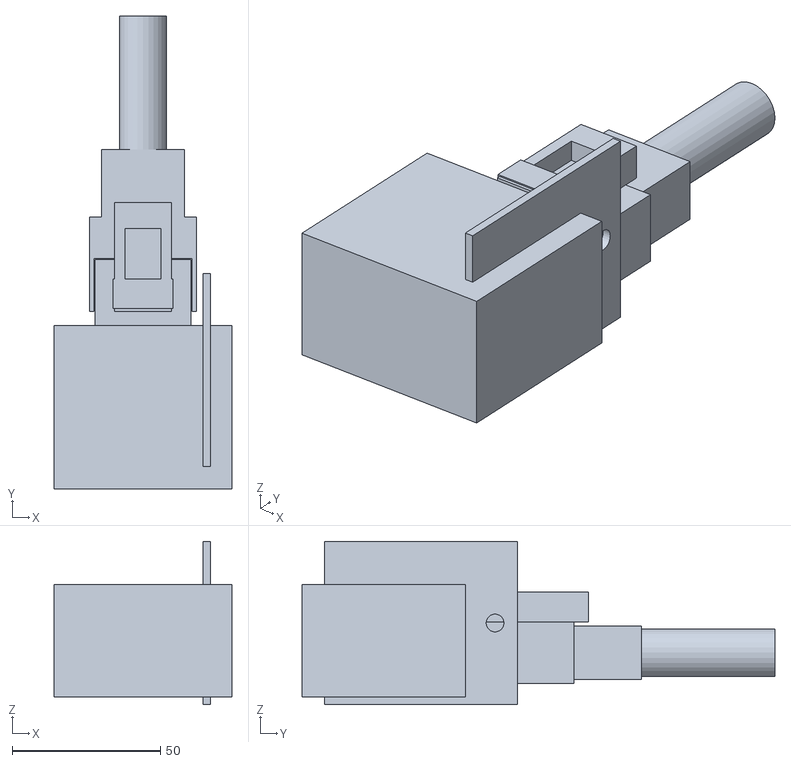
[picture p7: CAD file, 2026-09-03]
testing/seated_assembly.stl
60.0 x 159.3 x 55.0

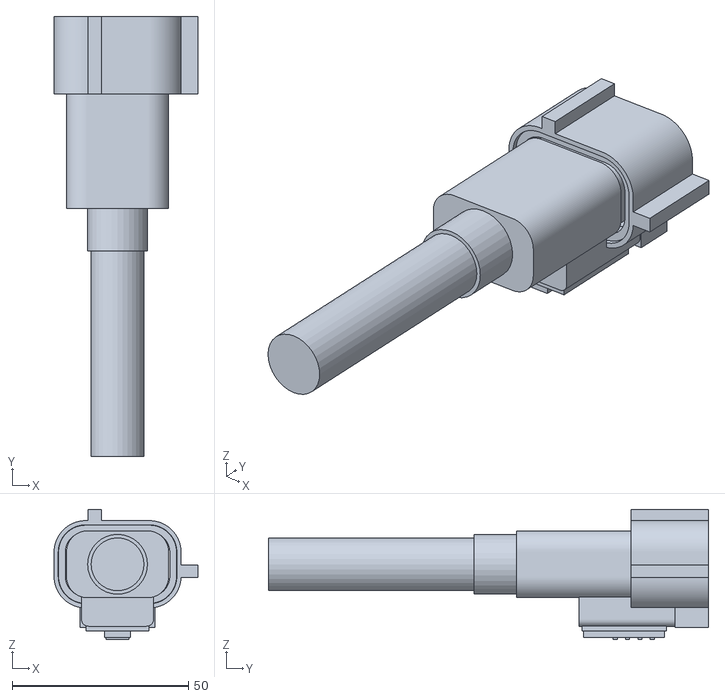
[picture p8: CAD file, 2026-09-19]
accurate_models/mated_connector.stl
40.9 x 125.0 x 37.0

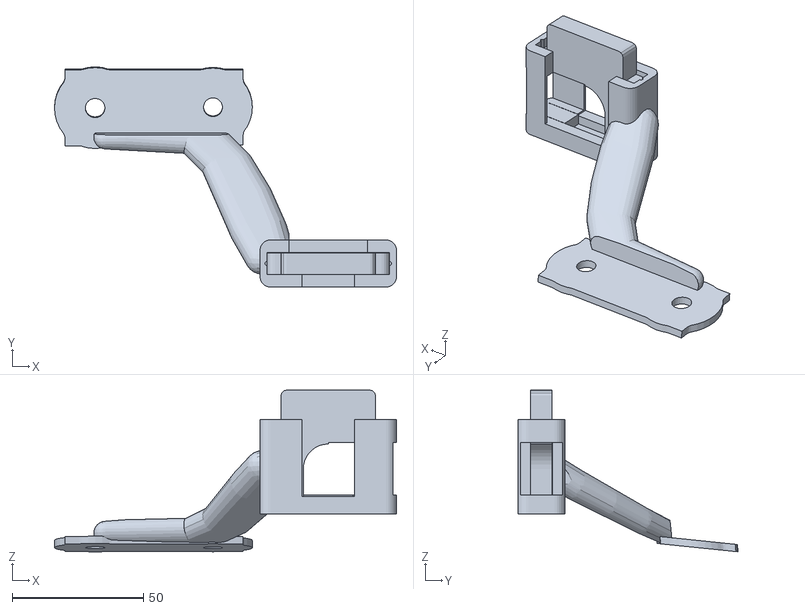
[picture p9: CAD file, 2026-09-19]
lock_v2/lock_v2_1piece_monolithic.stl
130.3 x 83.9 x 61.6

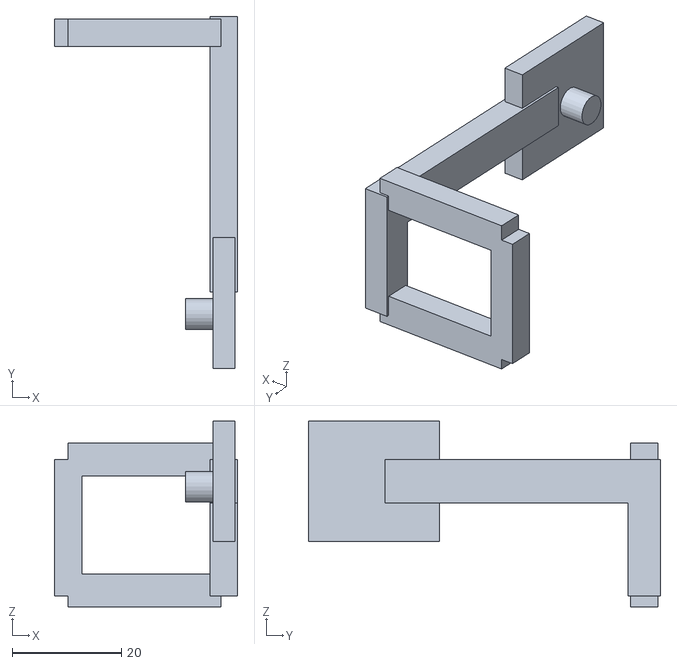
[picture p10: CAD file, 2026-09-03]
testing/concept3_chassis_bracket_retainer.stl
33.5 x 64.5 x 34.0

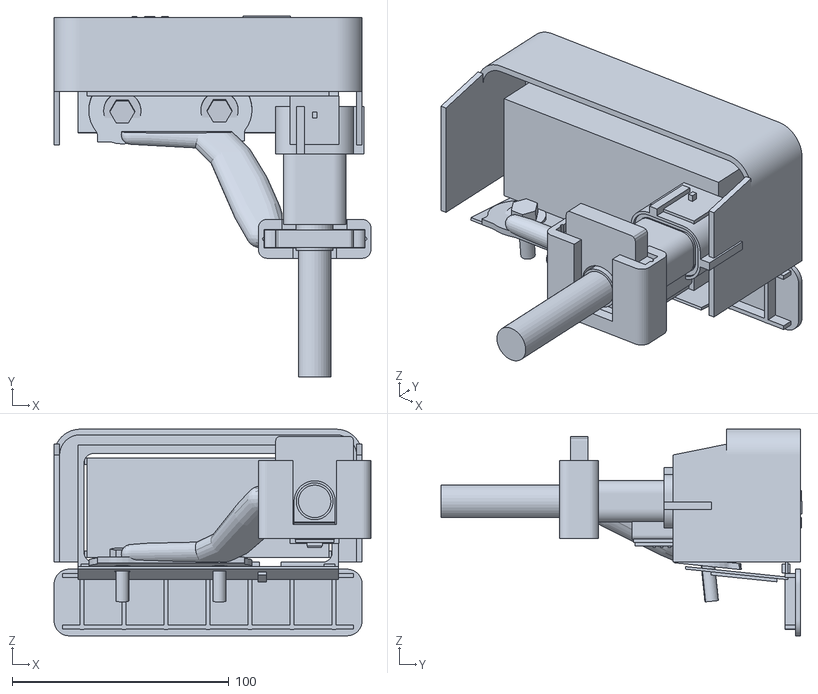
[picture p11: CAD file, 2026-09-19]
lock_v2/lock_v2_mated_verification.stl
146.3 x 166.7 x 95.4

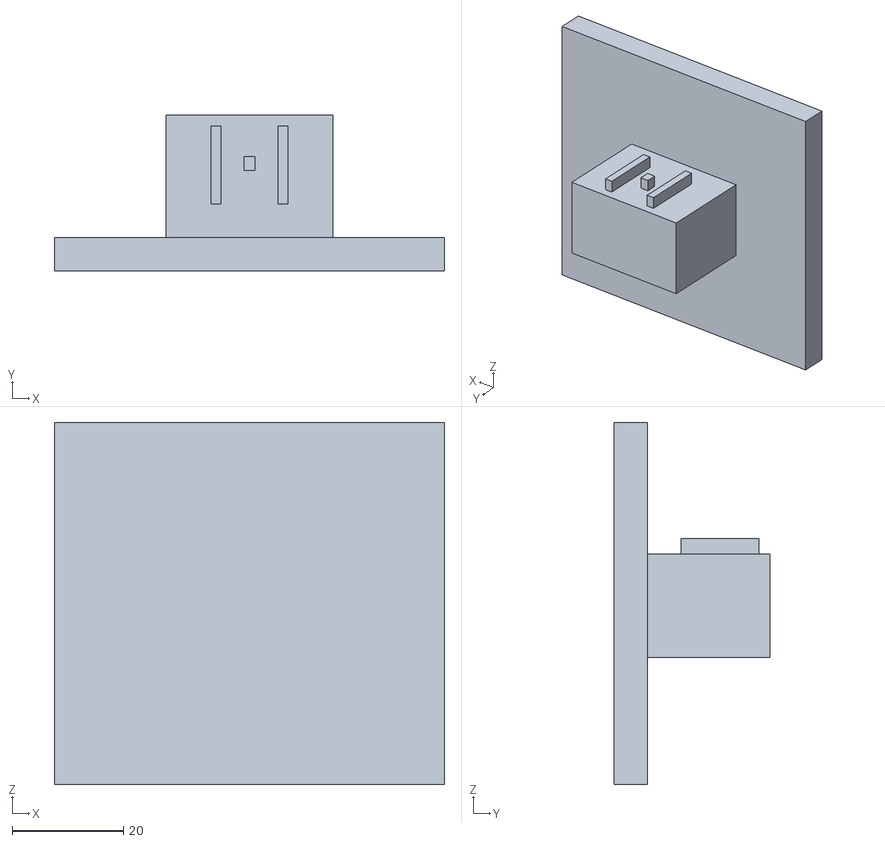
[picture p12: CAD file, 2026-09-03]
testing/context_housing.obj
70.0 x 28.0 x 65.0

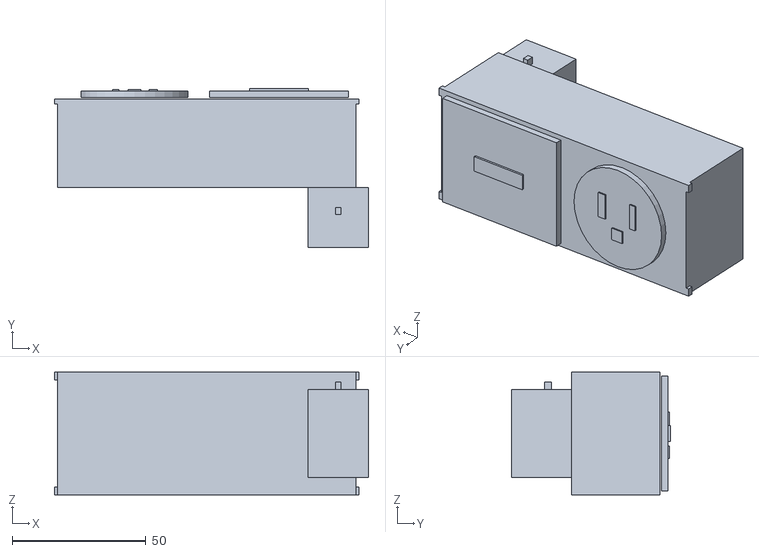
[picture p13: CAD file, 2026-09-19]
accurate_models/mated_outlet_box.stl
117.5 x 59.4 x 46.0

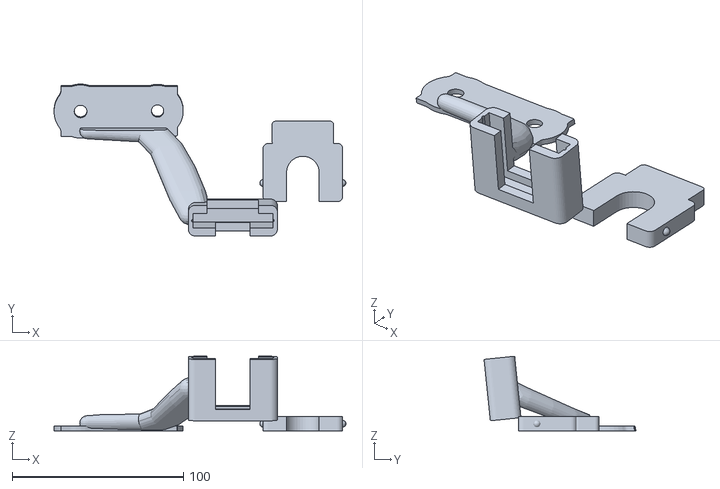
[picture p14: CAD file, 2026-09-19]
lock_v2/lock_v2_print_plate.stl
170.3 x 88.7 x 43.5

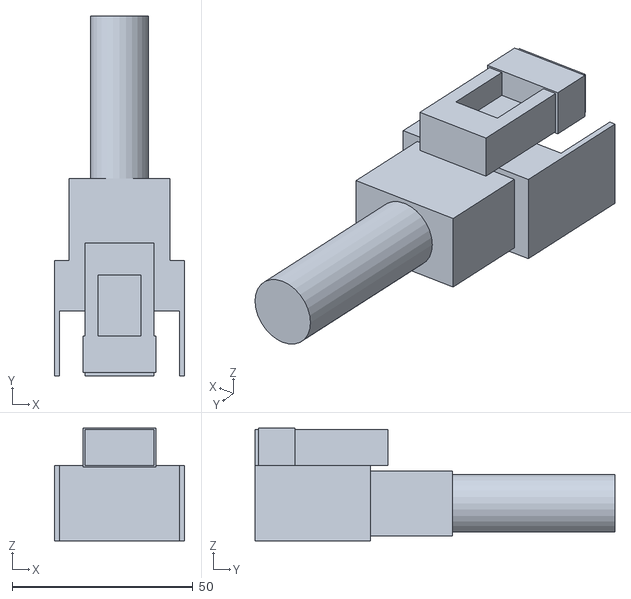
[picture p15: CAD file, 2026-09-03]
testing/seated_connector.stl
36.1 x 99.6 x 31.2

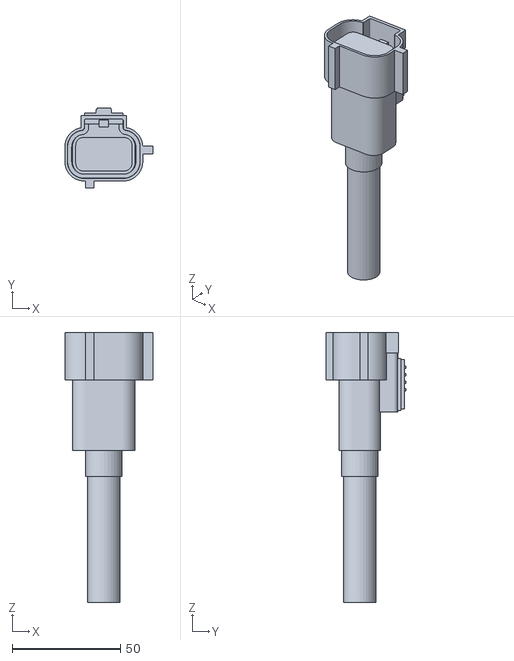
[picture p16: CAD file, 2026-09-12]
accurate_models/connector_model.stl
40.9 x 37.0 x 125.0

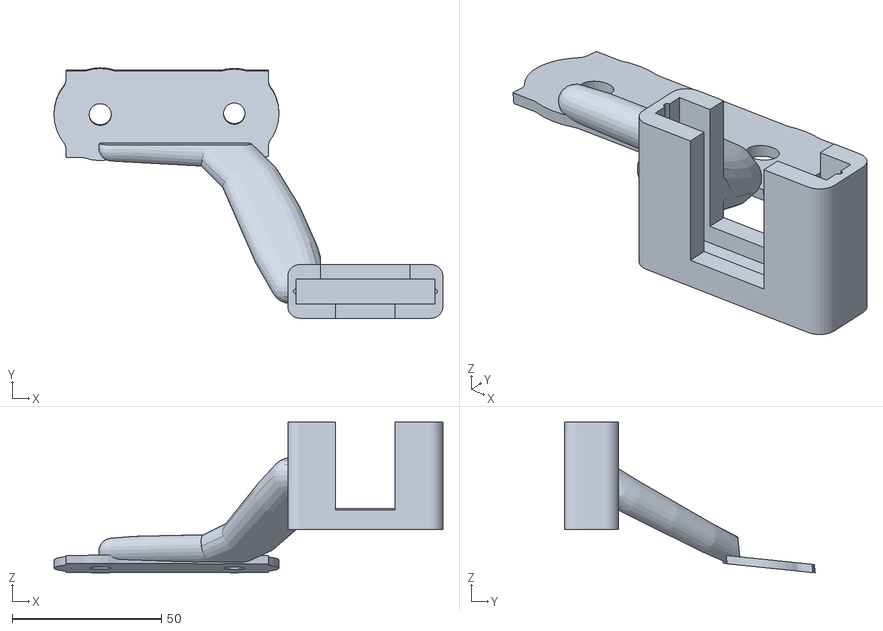
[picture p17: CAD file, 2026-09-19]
lock_v2/lock_v2_base_bracket.stl
130.3 x 83.9 x 50.5

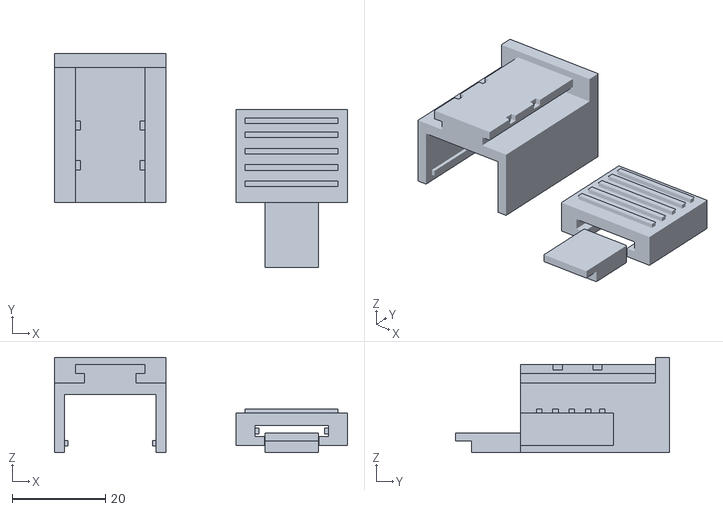
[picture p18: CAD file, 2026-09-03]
testing/hv_lock_plate.stl
62.9 x 46.0 x 20.5

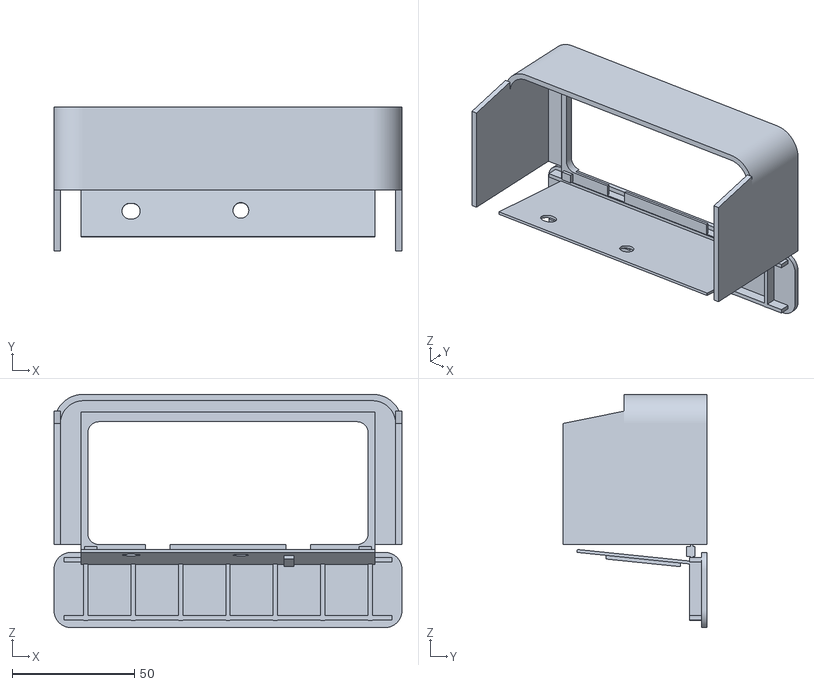
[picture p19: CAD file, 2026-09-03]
accurate_models/mated_outer_housing.stl
142.3 x 58.8 x 95.4

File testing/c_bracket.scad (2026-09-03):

// ==============================================================================
// c_bracket.scad
// Parametric OpenSCAD Source for Vehicle-Accurate Right-Hand Corner C-Bracket
// Kia EV6 / E-GMP 95190-CV780 Outlet Box & V2L Connector Lock
// ==============================================================================

$fn = 40;

// Housing & Seated Plug Calibrated Dimensions (mm)
BOX_W = 111.75;         // Long width across car (extends to the left)
BOX_D = 48.15;          // Front-to-back depth (120V face to rear connector face)
BOX_H = 42.67;          // Vertical height (bottom to top lid)
LID_OH = 12.45;         // Rear lid lip overhang
LID_T = 4.58;           // Lid lip vertical thickness

CONN_W = 36.10;         // Orange plug width
CONN_L = 54.60;         // Rigid body length to shoulder
SEATED_GAP = 4.70;      // Front rim to housing gap
PLUG_SHOULDER_Y = SEATED_GAP + CONN_L; // 59.30 mm

CABLE_R = 8.50;         // Cable boot radius (~17mm diameter)
WALL_T = 4.00;          // Structural wall thickness
BRACKET_W = CONN_W + 12.0; // 48.10 mm (Right-hand corner span)

module vehicle_c_spine() {
    difference() {
        union() {
            // 1. Top Plate (Rests on lid above right-hand corner)
            translate([-BRACKET_W, -(BOX_D + LID_OH), BOX_H])
                cube([BRACKET_W, BOX_D + LID_OH + WALL_T, WALL_T]);
            
            // 2. Positive Hook (Catches 12.45mm rear lid overhang)
            translate([-BRACKET_W, -LID_OH - WALL_T, BOX_H - (LID_T + 4.0)])
                cube([BRACKET_W, WALL_T, LID_T + 4.0]);
            
            // 3. Right Outer Flank (Wraps exterior right end of the box)
            translate([0, -(BOX_D + LID_OH), -15.0])
                cube([WALL_T, BOX_D + LID_OH + PLUG_SHOULDER_Y + 10.0, BOX_H + WALL_T + 15.0]);
            
            // 4. Rear Drop Arm at Plug Shoulder
            translate([-BRACKET_W, PLUG_SHOULDER_Y, -15.0])
                cube([BRACKET_W, WALL_T + 4.0, BOX_H + WALL_T + 15.0]);
            
            // 5. Track Housing at Bottom
            translate([-BRACKET_W - 2.0, PLUG_SHOULDER_Y, -15.0])
                cube([BRACKET_W + 4.0, 12.0, 16.0]);
        }
        
        // Slide track slot for Keeper (open on left side)
        translate([-BRACKET_W - 10.0, PLUG_SHOULDER_Y + 3.0, -13.0])
            cube([BRACKET_W + 15.0, 7.0, 12.0]);
        
        // Cable exit cutout
        translate([-BRACKET_W/2, PLUG_SHOULDER_Y + 10.0, 0])
            rotate([90, 0, 0])
                cylinder(r = CABLE_R + 3.0, h = 40.0, center = true);
        
        // Connector clearance pocket
        translate([-BRACKET_W + 2.0, 0, -10.0])
            cube([CONN_W + 4.0, PLUG_SHOULDER_Y + 2.0, BOX_H + 5.0]);
    }
}

module slide_keeper() {
    difference() {
        union() {
            // Main Keeper Bar
            translate([-BRACKET_W, PLUG_SHOULDER_Y + 3.5, -12.0])
                cube([BRACKET_W, 6.0, 13.0]);
            
            // Ergonomic Thumb Pull Tab (on left accessible side)
            translate([-BRACKET_W - 10.0, PLUG_SHOULDER_Y + 2.0, -12.0])
                cube([10.0, 9.0, 16.0]);
        }
        
        // Cable Cradle Slot (U-cutout)
        translate([-BRACKET_W/2, PLUG_SHOULDER_Y + 6.0, -6.0])
            rotate([90, 0, 0])
                cylinder(r = CABLE_R + 1.2, h = 25.0, center = true);
        translate([-BRACKET_W/2 - (CABLE_R + 1.2), PLUG_SHOULDER_Y - 5.0, -6.0])
            cube([2 * (CABLE_R + 1.2), 25.0, 18.0]);
    }
}

// Render Assembled State
color([0.05, 0.52, 0.78, 0.95]) vehicle_c_spine();
color([0.13, 0.77, 0.37, 0.95]) slide_keeper();

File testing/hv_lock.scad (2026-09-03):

// ==============================================================================
// Kia EV6 / E-GMP V2L Exterior Cable Lock - OpenSCAD Parametric Source
// Calibrated from User Caliper Measurements
// ==============================================================================

// Dimensional Constants (mm)
tower_width = 19.06;        // [A3]
tower_length = 36.75;      // [B1]
tooth_dist = 8.73; // [C2]
tooth_width = 2.0;  // [C3]
tooth_height = 2.7;// [C4]
slide_stroke = 8.5;      // [B3]
clearance_slip = 0.35;  // FDM print clearance

// Modules
module saddle_base() {
    difference() {
        translate([0, 16, -4.5]) cube([23.96, 32, 15], center=true);
        translate([0, 16, -6.5]) cube([19.56, 34, 13], center=true);
    }
    translate([0, 16, 4]) cube([11, 32, 2], center=true);
    translate([0, 16, 6]) cube([15, 32, 2], center=true);
    translate([0, 30.5, 5]) cube([23.96, 3, 5.5], center=true);
}

module sliding_deadbolt() {
    difference() {
        translate([0, 10, 6.5]) cube([23.96, 20, 7], center=true);
        translate([0, 10, 4]) cube([11.7, 22, 3.35], center=true);
        translate([0, 10, 6]) cube([15.7, 22, 2.35], center=true);
    }
    difference() {
        translate([0, -7, 3.6]) cube([11.5, 14, 4.2], center=true);
        translate([0, -8, 3.1]) cube([4, 3.5, 3.2], center=true);
    }
    for (y = [4, 7.5, 11, 14.5, 17.5]) {
        translate([0, y, 10.45]) cube([19.96, 1.2, 0.9], center=true);
    }
}

saddle_base();
translate([35, 0, 0]) sliding_deadbolt();

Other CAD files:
lock_v2/lock_v2_base_bracket_blown_floor.stl
accurate_models/outlet_box_model.stl
lock_v2/lock_v2_keeper.stl
testing/concept2_c_bracket_cage.stl
accurate_models/connector_model.obj
accurate_models/mated_assembly.obj
accurate_models/outer_housing_model.obj
accurate_models/outer_housing_model.stl
accurate_models/outlet_box_model.obj
lock_v2/lock_v2_1piece_monolithic.obj
lock_v2/lock_v2_base_bracket.obj
lock_v2/lock_v2_base_bracket_old.stl
lock_v2/lock_v2_keeper.obj
lock_v2/lock_v2_keeper_old.stl
lock_v2/lock_v2_mated_verification.obj
lock_v2/lock_v2_mated_verification_old.stl
lock_v2/lock_v2_print_plate.obj
testing/c_bracket_keeper.obj
testing/c_bracket_keeper.stl
testing/c_bracket_plate.obj
testing/c_bracket_plate.stl
testing/c_bracket_spine.obj
testing/c_bracket_spine.stl
testing/chassis_bolt_lock.obj
testing/chassis_bolt_lock.stl
testing/chassis_bolt_lock_print_ready.stl
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

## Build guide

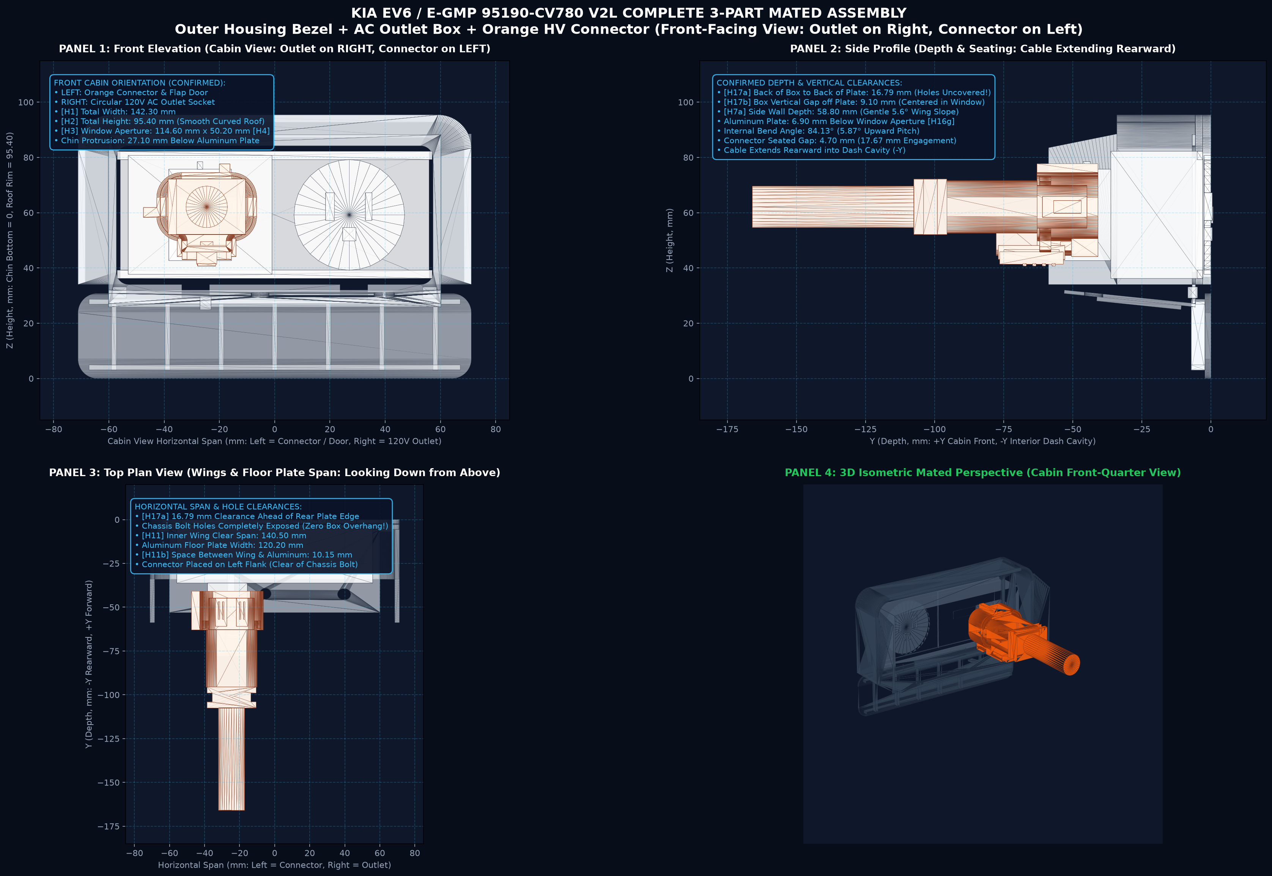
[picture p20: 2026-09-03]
accurate_models/mated_assembly_blueprint.png

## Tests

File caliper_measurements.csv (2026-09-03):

Group | Label | Feature Description | How to Measure with Calipers | Priority | Est. Range (mm) | Measured Value (mm) | Engineering Notes
Panel A: Plug Mating Face | [A1] | Shroud Outer Width | Widest outer horizontal span across orange oval shroud (exclude side key ribs) | Critical | 36 - 38 | 36.1 | Included tab
Panel A: Plug Mating Face | [A2] | Shroud Body Height | Outer vertical height of oval body (bottom wall to arch below tower) | Critical | 24 - 26 | 20.8 | Measured directly across oval
Panel A: Plug Mating Face | [A3] | Tower Outer Width | Outer horizontal width across the top rectangular latch tower | Critical | 14 - 16 | 19.06 | Tower channel alignment
Panel A: Plug Mating Face | [A4] | Total Plug Height | Bottom outer wall of oval shroud to top flat face of latch tower | Critical | 34 - 36 | 37.11 | Included tab (rib)
Panel A: Plug Mating Face | [A5] | Shroud Wall Thickness | Caliper inside-to-outside thickness of orange outer perimeter wall | Recommended | 1.5 - 2.0 | 1.2 | Internal clearance step
Panel A: Plug Mating Face | [A6] | Key Rib Protrusion | Distance the side alignment keying rib sticks out from outer oval wall | Recommended | 2.0 - 2.5 | 4.8 | Slot keyway relief
Panel B: Latch Tower & Slider | [B1] | Tower Axial Length | Length of top rectangular tower from front mating rim back to shoulder/tape | Critical | 18 - 22 | 36.75 | Slide carriage base length
Panel B: Latch Tower & Slider | [B2] | Slider Track Inner Width | Inside width of channel/cavity where orange slider sits | Critical | 10 - 12 | 17.8 | Internal channel width
Panel B: Latch Tower & Slider | [B3] | Slider Track Stroke Length | Usable linear stroke length of yellow slider track | Recommended | 8 - 12 | 8.25 | Slide travel range
Panel B: Latch Tower & Slider | [B4] | Slider Total Length | Overall length of detached orange slider piece | Critical | 15 - 18 | 23.0 | CPA slider replacement ref
Panel B: Latch Tower & Slider | [B5] | Slider Width | Width across main body / thumb pad of orange slider | Critical | 8 - 10 | 7.3 | CPA slider replacement ref
Panel B: Latch Tower & Slider | [B6] | Slider Thickness | Thickness / height of orange slider piece | Recommended | 3 - 4 | 4.45 | CPA slider replacement ref
Panel B: Latch Tower & Slider | [B7] | Body Rigid Length | Length of rigid orange housing from front rim to rear cable exit boot | Recommended | 45 - 55 | 54.6 | Defines rear shoulder position where keeper locks
Panel C: Outlet Receptacle | [C1] | Collar Protrusion Length | How far black receptacle collar extends outward from black backplate | Critical | 15 - 20 | 22.37 | Mating engagement depth
Panel C: Outlet Receptacle | [C2] | Tooth Distance from Rim | Distance from front mating rim of black collar to vertical latch tooth step | Critical | 8 - 11 | 8.73 | From farthest part of tooth which is sloped
Panel C: Outlet Receptacle | [C3] | Latch Tooth Width | Width of raised latch tooth / ramp | Critical | 3 - 5 | 2.0 | Locking tongue engagement
Panel C: Outlet Receptacle | [C4] | Latch Tooth Height | Height latch tooth protrudes above outer top surface of collar | Critical | 1.5 - 2.5 | 2.7 | Max height, since tooth is sloped
Panel C: Guide Ribs Spacing | [C5] | Guide Ribs Spacing | Outside width across the two guide ribs flanking the latch tooth | Recommended | 8 - 10 | 13.82 | Exterior dimension
Panel D: Receptacle Face & Clearances | [D1] | Collar Outer Width | Horizontal outer width across black protruding receptacle collar | Recommended | 32 - 34 | 22.7 | Includes alignment rib
Panel D: Receptacle Face & Clearances | [D2] | Collar Outer Height | Vertical outer height across black protruding receptacle collar | Recommended | 20 - 22 | 33.05 | Includes alignment rib
Panel D: Receptacle Face & Clearances | [D3] | Metal Plate Clearance | Distance from right edge of black collar to vertical silver metal plate | Recommended | 6 - 9 | 4.0 | Rough estimate
Panel D: Receptacle Face & Clearances | [D4] | Top Clearance | Free clearance above collar before hitting upper housing / wiring | Recommended | 10 - 15 | 8.27 | Measured from top of enclosure to top of outer receptacle
Panel E: Outlet Box Housing | [E1] | Box Height | Collar seating face up to top flat surface of the lid | Critical | 38 - 44 | 42.67 | Note: back of box is not flat where connector plugs in
Panel E: Outlet Box Housing | [E2] | Box Depth | Front vertical wall to rear vertical wall across box body | Critical | 45 - 52 | 48.15 | Distance from front face to rear hook anchor
Panel E: Outlet Box Housing | [E3a] | Lid Overhang Height | Vertical thickness / height of the overhanging lid rim | Critical | 3.0 - 5.0 | 4.58 | C-Spine hook drop height
Panel E: Outlet Box Housing | [E3b] | Lid Overhang Width | Horizontal distance the lid lip extends past the rear wall | Critical | 8.0 - 15.0 | 12.45 | C-Spine hook shelf width (massive positive engagement)
Panel E: Outlet Box Housing | [E4] | Box Width | Width across the black housing section | Critical | 48 - 56 | 49.65 | Determines C-Spine interior clearance width (51.5mm)
Panel E: Outlet Box Housing | [GAP] | Seated Gap | Distance between front face of connector and outlet housing when seated | Critical | 4.0 - 6.0 | 4.7 | Front connector clearance
Panel F: Outer Housing Bezel | [H1] | Total Outer Width | Widest horizontal span across outer housing edges | Critical | 140 - 180 | 142.3 | Confirmed caliper
Panel F: Outer Housing Bezel | [H2] | Total Outer Height | Bottom of lower chin to top outer rim face | Critical | 90 - 100 | 95.4 | Confirmed caliper
Panel F: Outer Housing Bezel | [H3] | Window Aperture Width | Inside horizontal opening where AC outlet sits | Critical | 112 - 125 | 114.6 | Confirmed caliper (>111.75mm outlet box)
Panel F: Outer Housing Bezel | [H4] | Window Aperture Height | Inside vertical height of rectangular opening | Critical | 48 - 58 | 50.2 | Confirmed caliper
Panel F: Outer Housing Bezel | [H5] | Lower Chin Height | Vertical thickness of protruding bottom bar | Recommended | 25 - 32 | 30.77 | Confirmed caliper
Panel F: Outer Housing Bezel | [H5b] | Chin Total Thickness | Front-to-back depth of chin including molded ribs in back | Critical | 6.0 - 8.5 | 7.1 | Confirmed caliper (user refined)
Panel F: Outer Housing Bezel | [H6] | Top Bezel Frame Thickness | Distance from top outer rim to top of window aperture | Recommended | 8 - 14 | 11.2 | Calculated from 95.40 - 84.20
Panel F: Outer Housing Bezel | [H7a] | Side Wall Depth | Front bezel face straight back to rear plastic edge of side wing | Critical | 55 - 65 | 58.8 | Confirmed caliper
Panel F: Outer Housing Bezel | [H9] | Top Shelf Flat Length | Length of horizontal top section before angled drop | Recommended | 30 - 40 | 34.0 | Confirmed caliper
Panel F: Outer Housing Bezel | [H10] | Aluminum Rear Extension | Distance silver sheet metal clip extends backwards | Recommended | 45 - 55 | 53.0 | Confirmed caliper
Panel F: Outer Housing Bezel | [H11] | Inner Wing Clear Span | Clear inside width between left and right side walls | Critical | 135 - 145 | 140.5 | Confirmed caliper
Panel F: Outer Housing Bezel | [H11b] | Wing to Aluminum Space | Horizontal clearance between plastic wing and horizontal aluminum plate | Critical | 9.0 - 11.5 | 10.15 | Confirmed caliper (user refined)
Panel F: Outer Housing Bezel | [H12] | Aluminum Bracket Width | Width of horizontal stamped sheet metal frame | Critical | 118 - 125 | 120.2 | 140.50 - 2x10.15 = 120.20mm
Panel F: Outer Housing Bezel | [H13] | Side Wall Thickness | Plastic wall thickness of the side wings | Recommended | 2.0 - 3.0 | 2.6 | Confirmed caliper
Panel F: Outer Housing Bezel | [H14] | Window Recess Step Depth | Depth of internal ledge where outlet face seats | Recommended | 2.5 - 4.0 | 3.0 | Confirmed caliper
Panel F: Outer Housing Bezel | [H15a] | Aluminum Outer Hole Offset | Distance from side of aluminum to outer edge of horizontal oval slot | Critical | 14 - 18 | 16.75 | Confirmed caliper
Panel F: Outer Housing Bezel | [H15b] | Aluminum Outer Oval Width (X) | Width of horizontal oval slot along X (rotated 90 deg) | Critical | 6.5 - 8.5 | 7.45 | Confirmed caliper (horizontal slot)
Panel F: Outer Housing Bezel | [H15c] | Aluminum Holes Edge Spacing | Distance from inner edge of oval slot to outer edge of central hole | Critical | 35 - 40 | 37.95 | Confirmed caliper
Panel F: Outer Housing Bezel | [H15d] | Aluminum Central Hole Diameter | Diameter of central circular round hole through aluminum floor | Critical | 5.5 - 7.5 | 6.45 | Confirmed caliper
Panel F: Outer Housing Bezel | [H15e] | Aluminum Holes Center Spacing | Center-to-center distance between the two holes | Critical | 40 - 50 | 44.9 | Calculated center-to-center
Panel F: Outer Housing Bezel | [H15f] | Central Hole Back Edge Dist | Distance from back edge of aluminum to central hole | Critical | 6.0 - 9.0 | 7.6 | Confirmed caliper (7.6mm to back edge)
Panel F: Outer Housing Bezel | [H15g] | Outer Oval Back Edge Dist | Distance from back edge of aluminum to outer horizontal oval slot | Critical | 6.0 - 9.0 | 7.3 | Confirmed caliper (7.3mm to back edge)
Panel F: Outer Housing Bezel | [H16a] | 50mm Triangle Chord Distance | Distance between 50mm marks on traced angle legs | Critical | 64 - 70 | 67.0 | Confirmed caliper (chord C=67mm)
Panel F: Outer Housing Bezel | [H16b] | Internal Bend Angle | Calibrated internal bend angle of aluminum plate | Critical | 82 - 86 | 84.13 | 2 * arcsin(67/100) = 84.13 deg
Panel F: Outer Housing Bezel | [H16c] | Upward Pitch Angle | Upward tilt angle of aluminum plate toward ceiling | Critical | 4.0 - 8.0 | 5.87 | 90.0 - 84.13 = 5.87 deg pitch
Panel F: Outer Housing Bezel | [H16d] | Wing Bottom Termination | Vertical height where side wings terminate (aligned with window) | Critical | 32 - 36 | 34.0 | Aligned with window bottom
Panel F: Outer Housing Bezel | [H16f] | Chin Below Aluminum Plate | Vertical distance chin extends down below aluminum plate | Critical | 25 - 29 | 27.1 | Confirmed caliper (chin extends 27.1mm)
Panel F: Outer Housing Bezel | [H16g] | Plate Below Window Aperture | Vertical distance aluminum plate is below window opening | Critical | 6.0 - 8.0 | 6.9 | Confirmed caliper (plate 6.9mm below window)
Panel F: Outer Housing Bezel | [H17a] | Back of Box to Back of Plate | Horizontal distance from back of aluminum plate forward to back wall of outlet box | Critical | 15 - 18 | 16.79 | Leaves 16.79mm of rear plate clear so chassis bolt holes are completely uncovered
Panel F: Outer Housing Bezel | [H17b] | Box Vertical Gap off Plate | Vertical clearance between bottom surface of outlet box and near horizontal aluminum plate | Critical | 8 - 10 | 9.1 | Bottom of box sits ~9.1mm above aluminum plate (2.2mm above window bottom sill)

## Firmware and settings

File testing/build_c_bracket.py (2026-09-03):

"""
build_c_bracket.py
Parametric 3D CAD generator for the Heavy-Duty Concept 2 C-Bracket Cage with Toolless Slide-In Keeper.
Bridges the black outlet housing box directly to the orange cable connector's rear shoulder (B7 = 54.6mm).
Produces 100% manifold, watertight STLs designed for support-free FDM printing in PETG/ABS/ASA.
"""

import math
import numpy as np
import trimesh
import matplotlib.pyplot as plt
from mpl_toolkits.mplot3d.art3d import Poly3DCollection
import os

target_dir = r"c:\Users\Elliot\Documents\antigravity\hv_lock"
artifact_dir = r"C:\Users\Elliot\.gemini\antigravity\brain\bcff0673-e2b6-492e-8df2-3d38d1a52185"

def create_box(extents, translation=[0, 0, 0]):
    m = trimesh.creation.box(extents=extents)
    m.apply_translation(translation)
    return m

def create_cylinder(radius, height, translation=[0, 0, 0], transform=None):
    m = trimesh.creation.cylinder(radius=radius, height=height, sections=32)
    if transform is not None:
        m.apply_transform(transform)
    m.apply_translation(translation)
    return m

# ==============================================================================
# CALIBRATED DIMENSIONS (from User Calipers & Seated Photos)
# ==============================================================================
# Outlet Housing Box
BOX_W = 60.0             # Width across housing box
BOX_L = 48.0             # Depth of housing box from backplate (Y in [-48, 0])
BOX_H = 38.0             # Height of housing box (Z in [-14, 24])
BOX_LID_FLANGE_OVERHANG = 3.5 # Overhang of lid flange around perimeter
BOX_TOP_Z = 24.0         # Top plane of box lid

# Orange Connector Seated Position
SEATED_GAP = 4.70        # Gap between connector front rim and housing wall
PLUG_RIM_Y = 4.70        # Front rim of orange connector
PLUG_RIGID_L = 54.60     # Rigid body length [B7]
PLUG_SHOULDER_Y = PLUG_RIM_Y + PLUG_RIGID_L # 59.30 mm
SHROUD_W = 36.10         # Shroud outer width [A1]
SHROUD_H = 20.80         # Shroud height [A2]
CABLE_BOOT_R = 8.50      # Cable exit radius (~17mm diameter)

# Structural Wall Parameters
WALL_THICK = 4.00        # Main load-bearing wall thickness
RIB_THICK = 3.00         # Gusset/rib thickness
CLEARANCE = 1.00         # Assembly clearance fit around housing box

# ==============================================================================
# 1. BUILD PART 1: HEAVY-DUTY MONOLITHIC C-SPINE
# ==============================================================================
def build_spine():
    print("Generating Part 1: Heavy-Duty C-Spine...")
    
    # 1. Upper Box Hook
    # Sits on top of the housing box lid (Z in [BOX_TOP_Z + CLEARANCE, BOX_TOP_Z + CLEARANCE + WALL_THICK])
    # Hook overhangs the rear edge of the box (at Y = -BOX_L) to trap the lid flange
    hook_w = 48.0
    hook_len = 32.0
    hook_z = BOX_TOP_Z + CLEARANCE + WALL_THICK / 2.0 # 24 + 1 + 2 = 27.0
    top_plate = create_box([hook_w, hook_len, WALL_THICK], [0, -BOX_L / 2.0 - 4.0, hook_z])
    
    # Downward lip behind the box lid flange (drops down 7mm at Y = -BOX_L - 4.0)
    hook_lip = create_box([hook_w, WALL_THICK, 9.0], [0, -BOX_L - 2.0, hook_z - 4.5])
    
    # 2. Main Structural Spine (U-channel running forward from box top down past the connector)
    # Forward top bridge (from Y = -BOX_L / 2 forward to Y = PLUG_SHOULDER_Y + 12.0)
    spine_total_len = (PLUG_SHOULDER_Y + 12.0) - (-BOX_L / 2.0 + hook_len / 2.0) # ~75mm
    bridge_center_y = (-BOX_L / 2.0 + hook_len / 2.0 + PLUG_SHOULDER_Y + 12.0) / 2.0
    bridge_len = (PLUG_SHOULDER_Y + 12.0) - (-BOX_L / 2.0)
    top_bridge = create_box([hook_w, bridge_len, WALL_THICK], [0, bridge_center_y, hook_z])
    
    # 3. Heavy Stiffening Flanks (Left & Right vertical structural I-beam webs)
    # Flanks run all the way from Y = -10 forward to Y = PLUG_SHOULDER_Y + 8.0
    flank_x_l = -hook_w / 2.0 + WALL_THICK / 2.0
    flank_x_r = hook_w / 2.0 - WALL_THICK / 2.0
    flank_len = (PLUG_SHOULDER_Y + 10.0) - (-12.0)
    flank_center_y = (-12.0 + PLUG_SHOULDER_Y + 10.0) / 2.0
    
    # Side drop walls along both sides of the connector (Z in [-14, hook_z])
    drop_h = hook_z + 16.0 # ~43mm height
    drop_z = (hook_z - 16.0) / 2.0
    flank_l = create_box([WALL_THICK, flank_len, drop_h], [flank_x_l, flank_center_y, drop_z])
    flank_r = create_box([WALL_THICK, flank_len, drop_h], [flank_x_r, flank_center_y, drop_z])
    
    # Triangular reinforcement gussets (45 degree braces)
    gusset_l = create_box([RIB_THICK, 25.0, 18.0], [flank_x_l + WALL_THICK / 2.0 + RIB_THICK / 2.0, 20.0, hook_z - 9.0])
    gusset_r = create_box([RIB_THICK, 25.0, 18.0], [flank_x_r - WALL_THICK / 2.0 - RIB_THICK / 2.0, 20.0, hook_z - 9.0])
    
    # 4. Bottom Slide-In Keeper Guide Tracks
    # Located at Y in [PLUG_SHOULDER_Y, PLUG_SHOULDER_Y + 10.0] = [59.3, 69.3] mm
    # Grooved slots on inside faces of left and right flanks at Z in [-16.0, -6.0]
    track_housing_l = create_box([8.0, 10.0, 14.0], [flank_x_l + 2.0, PLUG_SHOULDER_Y + 5.0, -10.0])
    track_housing_r = create_box([8.0, 10.0, 14.0], [flank_x_r - 2.0, PLUG_SHOULDER_Y + 5.0, -10.0])
    
    # Assemble spine solid
    spine = top_plate.union([hook_lip, top_bridge, flank_l, flank_r, gusset_l, gusset_r, track_housing_l, track_housing_r], engine='manifold')
    
    # Cut horizontal slide tracks on inside faces for the Keeper to slide in from the side (X-axis slide)
    # Track profile: 5.0mm tall, 3.5mm deep, with 45-degree dovetail chamfer
    track_cutout = create_box([hook_w + 10.0, 6.5, 6.0], [0, PLUG_SHOULDER_Y + 5.0, -10.0])
    spine = spine.difference(track_cutout, engine='manifold')
    
    # Cable clearance cutout at bottom rear
    rot_x = trimesh.transformations.rotation_matrix(np.pi / 2, [1, 0, 0])
    cable_cut = create_cylinder(radius=CABLE_BOOT_R + 3.0, height=35.0,
                                translation=[0, PLUG_SHOULDER_Y + 10.0, 0], transform=rot_x)
    spine = spine.difference(cable_cut, engine='manifold')
    
    return spine
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

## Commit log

2026-09-03 Initial commit: High-fidelity vehicle outlet CAD models, outer housing bezel, and lock mechanisms
    [c_bracket.scad, c_bracket_keeper.obj, c_bracket_keeper.stl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]
2026-09-03 Add complete 3-part mated assembly: Outer Housing Bezel + AC Outlet Box + Orange HV Connector
    [mated_assembly.obj, mated_assembly.stl, mated_connector.stl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]
2026-09-03 Fix mated assembly blueprint projection: Outlet on Right, Connector on Left
2026-09-03 Update mated assembly with physical caliper clearances: H17a (16.79mm back-of-box offset) and H17b (9.10mm vertical gap off plate)
    [caliper_measurements.csv, caliper_measurements.xlsx, mated_assembly.obj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]
2026-09-03 Fix mated_outlet_box mirroring: Outlet on Right, Connector on Left
    [mated_assembly.obj, mated_assembly.stl, mated_connector.stl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]
2026-09-03 Move all testing, prototype, and historical files to testing/ subfolder
    [c_bracket.scad, c_bracket_keeper.obj, c_bracket_keeper.stl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]
2026-09-04 feat(lock_v2): Add continuous organic connector lock system with aligned detents and optimized print plate
    [lock_v2_1piece_monolithic.obj, lock_v2_1piece_monolithic.stl, lock_v2_base_bracket.obj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]
2026-09-04 feat(lock_v2): Redesign keeper as 100% open-bottom inverted U-fork (Genus=0, zero closed holes)
    [lock_v2_1piece_monolithic.obj, lock_v2_1piece_monolithic.stl, lock_v2_base_bracket.obj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]
2026-09-04 feat(lock_v2): Upgrade base bracket with heavy-duty organic monocoque riser backbone
    [lock_v2_1piece_monolithic.obj, lock_v2_1piece_monolithic.stl, lock_v2_base_bracket.obj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]
2026-09-10 feat(lock_v2): Unify bolt interface and spine with 8.5mm turrets and continuous deck
    [lock_v2_1piece_monolithic.obj, lock_v2_1piece_monolithic.stl, lock_v2_base_bracket.obj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]
2026-09-12 feat(lock_v2): Calibrate bilateral bearing shoulders and snug cradle channel
    - Tighten keeper throat to 19.0 mm centered on connector handle axis (X=24.60, Z=62.10 mm)
    - Establish 5.0 mm solid bilateral bearing shoulders (>160 mm² contact, 1.000 symmetry ratio)
    - Narrow cradle guide channel to 30.0 mm (0.5 mm slip-fit) to eliminate twist and rattle
    - Update connector clamp collar in accurate_models to 17.0 mm cable diameter
    - Rebuild all production deliverables, Bambu P1S print plate, and 5K blueprint
    [connector_model.obj, connector_model.stl, lock_v2_1piece_monolithic.obj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]
2026-09-12 feat(lock_v2): Flatten bolt interface at depressions and calibrate 5.8mm lateral offset
    - Flatten bolt mounting flange to uniform 2.80 mm planar thickness starting at bolt depressions to eliminate interference with vehicle stamped aluminum plate
    - Set back Wishbone riser spine roots behind bolt depressions and aluminum floor plate (v >= 47.0 mm, Y <= -52.0 mm)
    - Realign retention cradle, guide tracks, and keeper 5.8 mm to the left (X = 21.20 mm) based on physical vehicle test-fitting
    - Establish 8.55 mm solid bilateral bearing shoulders (~325 mm contact area, 1.000 symmetry ratio)
    - Regenerate all watertight STLs, OBJs, mated verification assembly, Bambu P1S print plate, and 5K technical blu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
    [lock_v2_1piece_monolithic.obj, lock_v2_1piece_monolithic.stl, lock_v2_base_bracket.obj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]
2026-09-12 feat(lock_v2): Resmooth arm with base shelf, extend tracks full-depth, and enable friction-fit keeper
    - Resmooth connecting arm to slim organic profile (31,446 mm volume, 28% mass reduction)
    - Add 5.5 mm base reinforcement gusset shelf directly behind aluminum plate
    - Extend guide tracks all the way down through cradle bottom (Z = 40 mm) eliminating premature bottoming out
    - Widen keeper to 46.50 mm (0.05 mm precision slide fit) and tighten track depth to 8.45 mm
    - Increase male detent bumps to R = 2.0 mm snapping under solid 1.5 mm retention shelf
    - Rebuild all production CAD models, Bambu P1S plate, and 5K blueprint
    [lock_v2_1piece_monolithic.obj, lock_v2_1piece_monolithic.stl, lock_v2_base_bracket.obj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]
2026-09-12 fix(lock_v2): Revert full-depth track extension to retain floor at Z=48mm
    [lock_v2_1piece_monolithic.obj, lock_v2_1piece_monolithic.stl, lock_v2_base_bracket.obj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]
2026-09-19 feat(lock_v2): Calibrate +28mm cabin-leftward shift and 2.5mm fore-aft reach relief with top-down comparison
    [lock_v2_1piece_monolithic.obj, lock_v2_1piece_monolithic.stl, lock_v2_base_bracket.obj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]
2026-09-19 fix(lock_v2): Restore solid cradle floor at Z=51.5mm under cable channel
    [lock_v2_1piece_monolithic.obj, lock_v2_1piece_monolithic.stl, lock_v2_base_bracket.obj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]
2026-09-20 docs(lock_v2): Add orthographic cross-section visual illustrating restored cradle floor
    [lock_v2_base_bracket_blown_floor.stl]
